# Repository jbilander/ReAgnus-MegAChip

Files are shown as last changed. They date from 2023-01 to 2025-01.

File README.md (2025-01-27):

# ReAgnus-MegAChip
A ReAgnus MegaAChip PCB that takes a Gowin FPGA with embedded PSRAM, a PLCC-84 plug and FET level shifters.

***

THIS IS WORK IN PROGRESS, HARDWARE IS VERIFIED WORKING. FIRMWARE YET TO BE DEVELOPED. BUILD AT YOUR OWN RISK.

***

<a href="pics/ReAgnus-MegAChip_pic1.jpg">
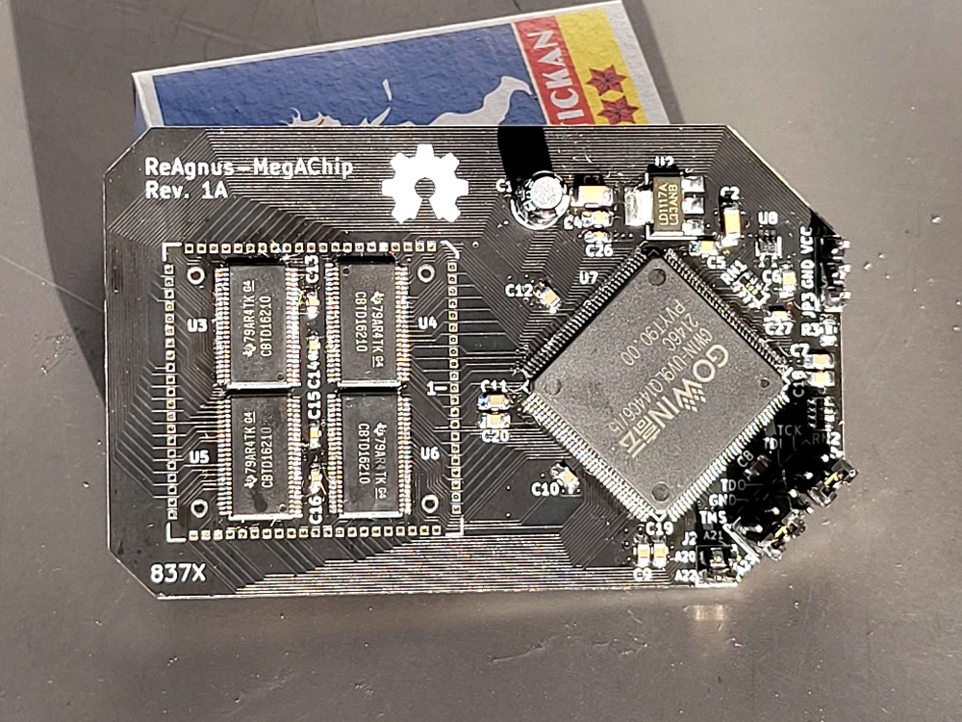
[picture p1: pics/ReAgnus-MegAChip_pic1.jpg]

</a>
<a href="pics/ReAgnus-MegAChip_pic21.png">
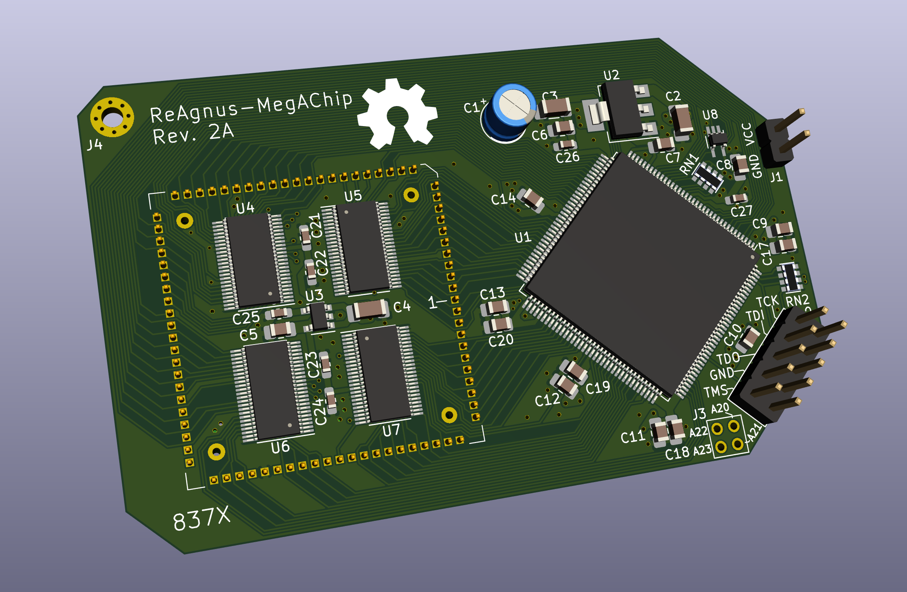
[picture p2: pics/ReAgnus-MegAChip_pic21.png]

</a>

***

<a href="pics/ReAgnus-MegAChip_pic2.jpg">
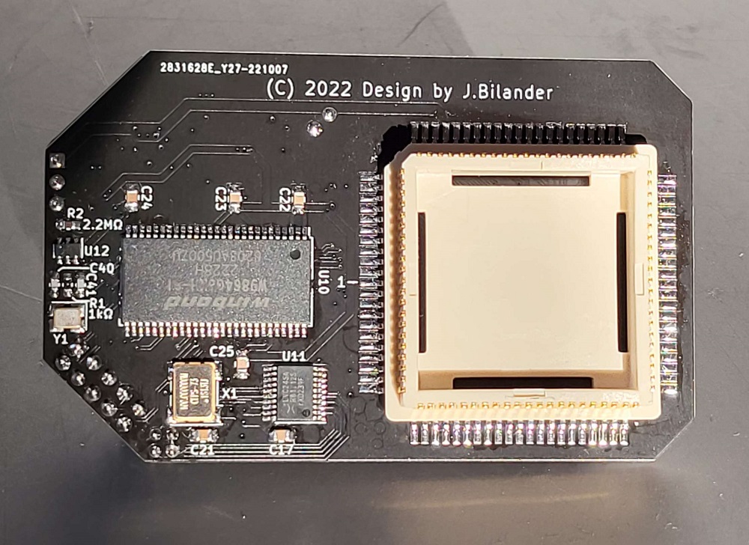
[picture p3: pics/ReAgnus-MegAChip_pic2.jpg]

</a>
<a href="pics/ReAgnus-MegAChip_pic22.png">
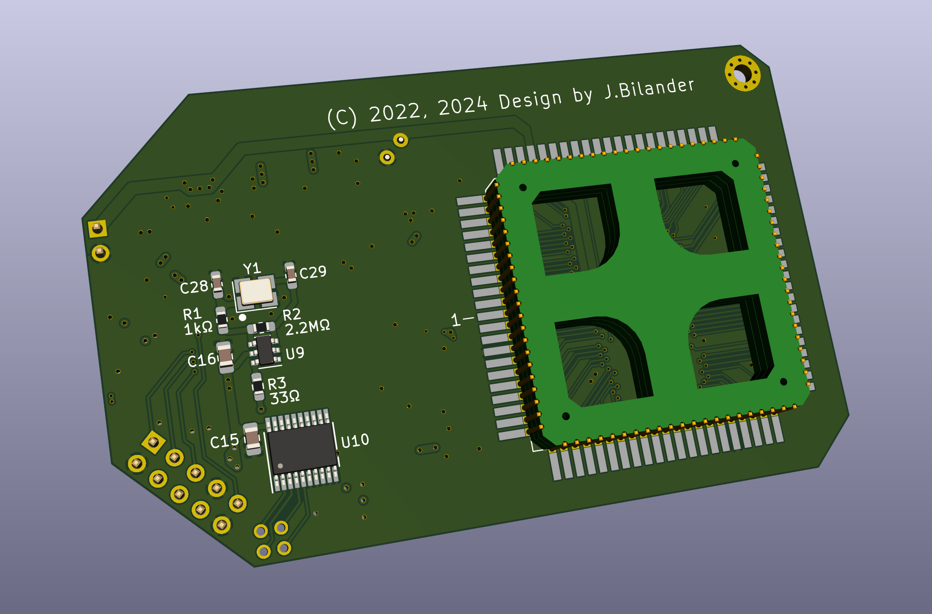
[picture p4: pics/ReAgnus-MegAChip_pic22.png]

</a>
<br />
<a href="pics/ReAgnus-MegAChip_pic23.png">
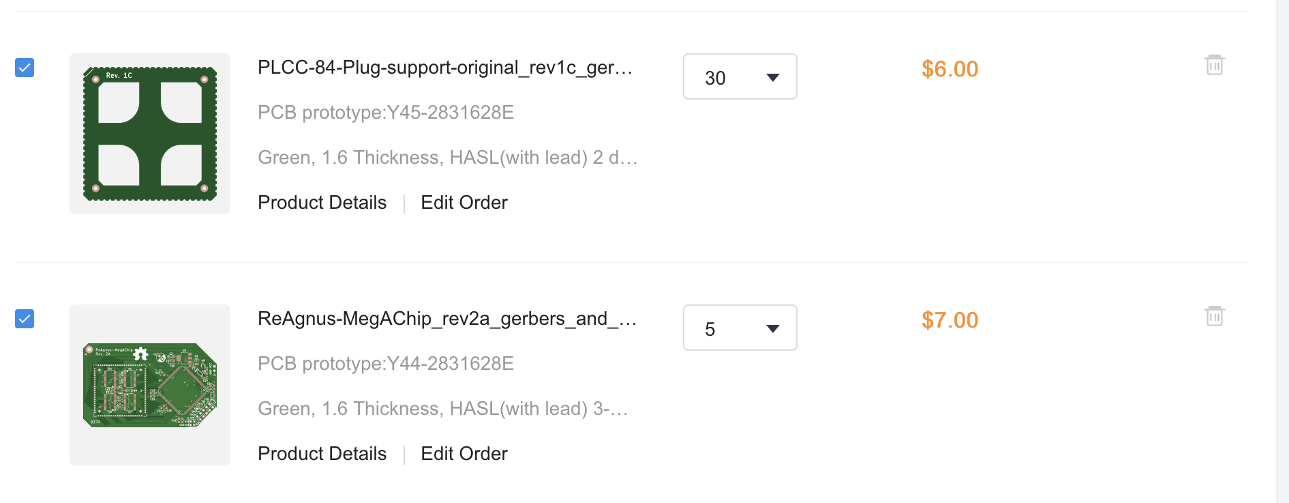
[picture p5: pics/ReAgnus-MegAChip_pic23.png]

</a>
<a href="pics/ReAgnus-MegAChip_pic24.png">
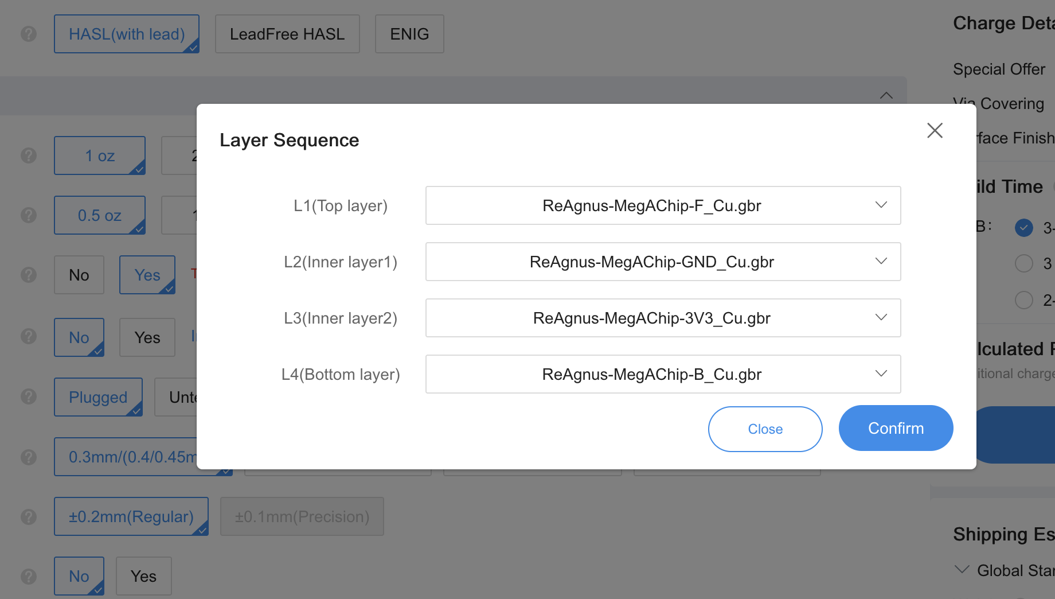
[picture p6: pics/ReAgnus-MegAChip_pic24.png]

</a>

***

***

For hi-res pics goto the hi-res folder in pics
https://github.com/jbilander/ReAgnus-MegAChip/tree/main/pics/hi-res

***

BOM Rev. 2C
---------
Designator  | Name/Value   | Package | Notes
-|-|-|-|
U1 | Gowin FPGA GW1NR-UV9LQ144PC6/I5 | LQFP-144 | FPGA - Field Programmable Gate Array, 8640 LE, 121 I/O, Embedded 64Mbit 16-bit PSRAM <br /> [GW1NR-UV9LQ144PC6/I5](https://www.mouser.com/ProductDetail/192-1NRUV9LQ144PC6I5)
U2 | Voltage Regulator 3.3V, <br /> LM1117-3.3 or <br /> AMS1117-3.3 | SOT-223 | 3.3V 1A Low Drop-Out (LDO) Voltage regulator. https://www.aliexpress.com/item/32869037691.html
U3 | Voltage Regulator 4.3V, TPS73643DBVR or <br /> ABLIC S-1132B43-M5T1U | SOT-23-5 | 4.3V LDO Voltage Regulator<br />[TPS73643DBVR](https://www.mouser.com/ProductDetail/595-TPS73643DBVR) <br />[S-1132B43-M5T1U](https://www.mouser.com/ProductDetail/628-S-1132B43-M5T1G)
U4,U5,U6,U7 | Digital Bus Switch ICs 20-Bit FET, SN74CBT16210CDGVR | TVSOP-48 | FET Level-shifter <br /> [SN74CBT16210CDGVR](https://www.mouser.com/ProductDetail/595-SN74CBT16210CDGV)
U8 | 74LVC1G07 Single Buffer With Open-Drain Output | SOT-353, SC-70-5 | [74LVC1G07](https://www.mouser.com/ProductDetail/621-74LVC1G07SE-7)
U9 | X-tal driver 74LVC1GX04  | TSOP-6 1.65x3.05mm P0.95mm | [74LVC1GX04](https://www.mouser.com/ProductDetail/771-LVC1GX04GV125)
U10 | Bus Transceiver 74LVC245APW,118 | TSSOP-20 | [74LVC245APW-T](https://www.mouser.com/ProductDetail/771-74LVC245APW-T)
U11 | Voltage Regulator 1.8V, <br /> MCP1702T-1802E/CB | SOT-23 | 1.8V Low Drop-Out (LDO) Voltage regulator. [MCP1702T1802E-CB](https://www.mouser.com/ProductDetail/579-MCP1702T1802E-CB)
U12 | Winslow PLCC-84 Plug | PLCC-84 Plug | Optionally homemade plug
U13 | PLCC-84_TH_pin_holes | Agnus_TH_plug_pins | Pins to use with homemade plug, 1.27mm pitch Long Pin 1x40P or 1x50P [Aliexpress](https://www.aliexpress.com/item/32894911767.html) Cut to length after soldering.
Y1 | 18pF Crystal 28.6363 MHz (NTSC) or 28.375 MHz (PAL) | 3.2 mm x 2.5 mm | [ECS-286.3-18-33-JEM-TR](https://www.mouser.com/ProductDetail/520-286.3-18-33-JEMT) (NTSC)<br /> [ABM8-28.375MHZ-B2-T](https://www.mouser.com/ProductDetail/815-ABM8-28.375-B2-T) (PAL)
R1 | Resistor 1k Ω | 0603 | Resistor in optional Oscillator-circuit
R2 | Resistor 2.2M Ω | 0603 | Resistor in optional Oscillator-circuit
R3 | Resistor 33 Ω | 0603 | Series resistor for CLK from U9 to avoid reflections (in optional Oscillator-circuit).
R4 | Resistor 10k Ω | 0603 | Pull-up resistor for pin 41 (PAL/NTSC-selector for A500 Rev.6A/A2000/A3000-pinout) since A500 Rev.6A doesn't have pull-up on motherboard like A2000/A3000/A3000T have. Only needed for A500 Rev.6A. but doesn't hurt to populate anyway. 
R5 | Resistor 4.7k Ω | 0603 | Pull-down resistor for TCK in JTAG.
RN1 | 4.7k or 10k Ω RES ARRAY 4 Resistors | 1206 | [CAY16-4701F4LF](https://www.mouser.com/ProductDetail/652-CAY16A-4701F4LF) or [CAY16-103J4LF](https://www.mouser.com/ProductDetail/652-CAY16-103J4LF)
RN2 | 4.7k (CAY16-4701F4LF) RES ARRAY 4 Resistors | 1206 | [CAY16-4701F4LF](https://www.mouser.com/ProductDetail/652-CAY16A-4701F4LF)
C1 | Capacitor Radial Polarized 100uF | 2.5mm pitch, Through-Hole | [ECE-A0JKA101I](https://www.mouser.com/ProductDetail/667-ECE-A0JKA101I)
C2-C4 | Capacitor 10uF | 1206 | 
C5 | Capacitor 1uF | 0805 | 
C6 | Capacitor 10uF | 0805 |
C9 | Capacitor 1uF | 0805 |
C7,C8,C10-C16 | Capacitor 0.1uF = 100nF | 0805 |
C17-C19 | Capacitor 0.01uF = 10nF | 0805 (or 0603) |
C20 | Capacitor 0.1uF = 100nF | 0603 | Decoupling cap for U8
C21-C24 | Capacitor 0.1uF = 100nF | 0603 | Decoupling caps for U4-U7
C25 | Capacitor 0.1uF = 100nF | 0603 | Optional cap for U3, NR (Noise Reduction) pin 4 on TPS73643DBVR, this pin is NC on ABLIC S-1200B43-M5T1U
C26 | Capacitor 0.01uF = 10nF | 0603 |
C27-C28 | Capacitor 0.1uF = 100nF | 0603 |
C29-C30 | Multilayer Ceramic Capacitors MLCC - 32pF | 0603 | [06031A320FAT2A ](https://www.mouser.com/ProductDetail/581-06031A320FAT2A) Caps for optional oscillator circuit 
L1 | (Ferrite Bead 600ohms 100MHz .5A Monolithic) or 0 Ω resistor  | 0805 | [HZ0805E601R-10](https://www.mouser.com/ProductDetail/875-HZ0805E601R-10) or 0 Ω resistor 
J1 | VCC/GND Power Header Male | TH 1 x 2 Pin, 2.54mm pitch | For external power supply to allow programming of device when not plugged into the Amiga socket.
J2 | JTAG Pin Header Male | TH 2 x 5 Pin, 2.54mm pitch|
J3 | A20-A23 Pin Header Male | TH 2 x 2 Pin, 2.00mm pitch | Input Address lines for jumper-wires A20-A23
J4 | GND MountingHole_2.2mm_M2_Pad_Via | nut and bolt M2 size | for solid grounding via a ring lug connector and a thick jumper wire to Motherboard

***

Select one of the crystals 28.375 MHz (PAL) or 28.6363 MHz for the optional onboard oscillator circuit. Probably you want to select PAL/NTSC opposite to what your CLK on motherboard has, this in order to be able to switch between native PAL/NTSC with only a JP-setting on the MegaChip board.
***

<a href="pics/ReAgnus-MegAChip_pic5.png">
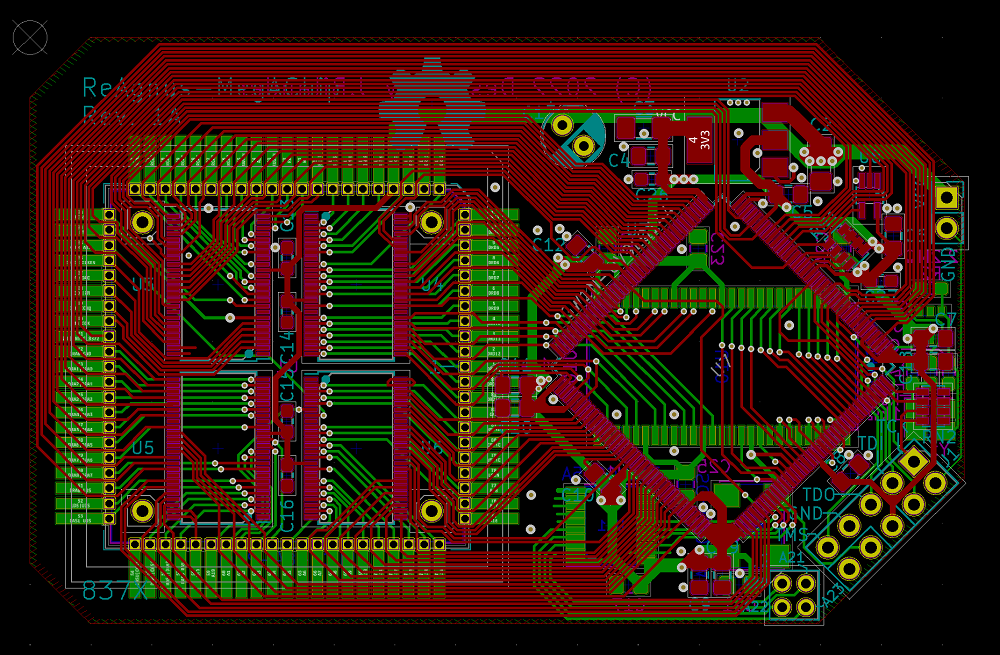
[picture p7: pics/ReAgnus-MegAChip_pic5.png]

</a>
<a href="pics/ReAgnus-MegAChip_pic6.png">
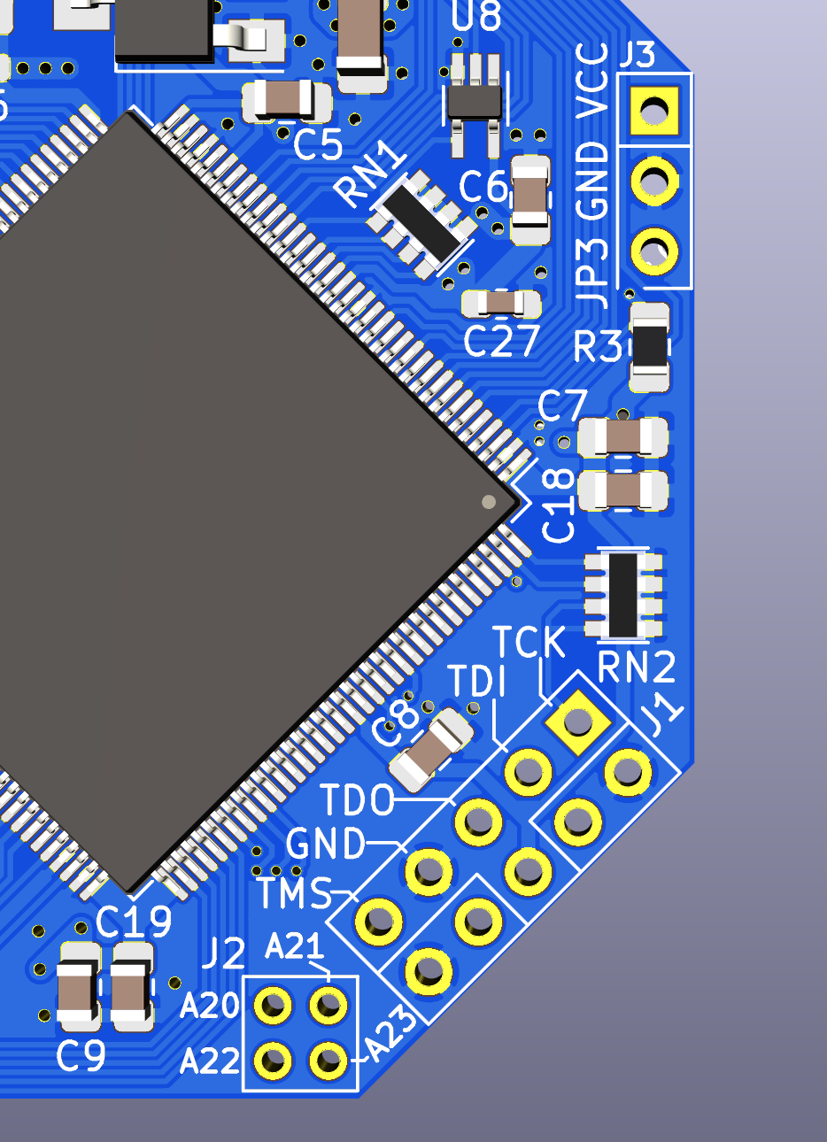
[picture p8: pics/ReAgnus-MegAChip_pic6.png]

</a>

***

<a href="pics/ReAgnus-MegAChip_pic7.jpg">
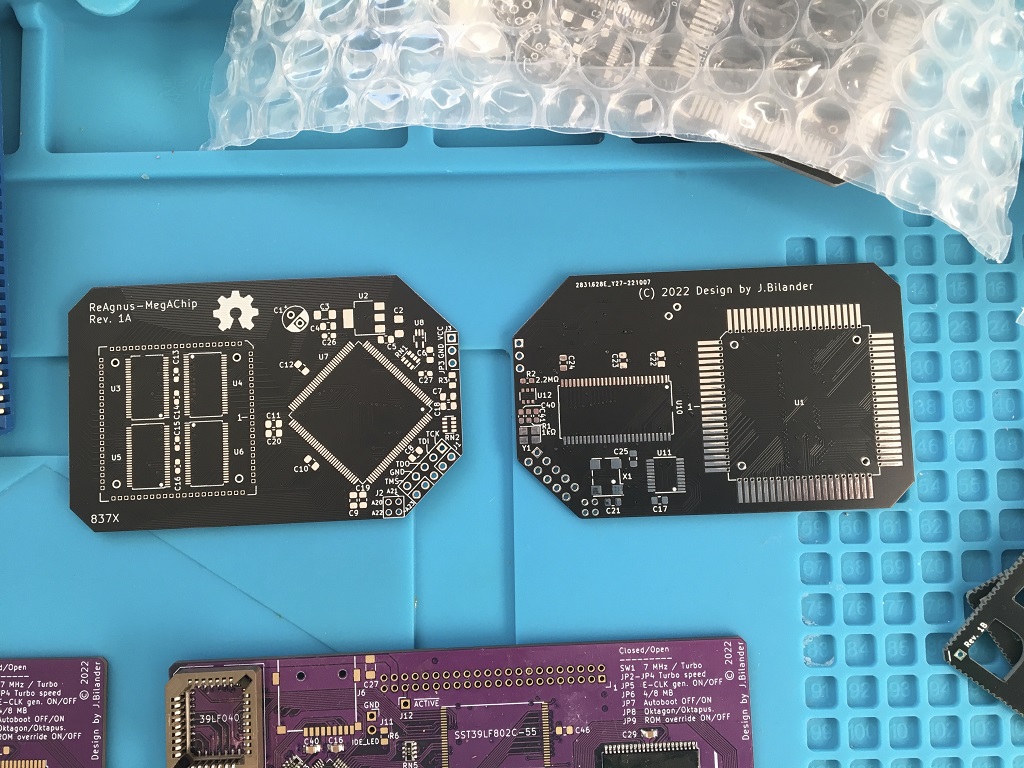
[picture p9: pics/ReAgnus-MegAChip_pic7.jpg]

</a>
<a href="pics/ReAgnus-MegAChip_pic8.jpg">
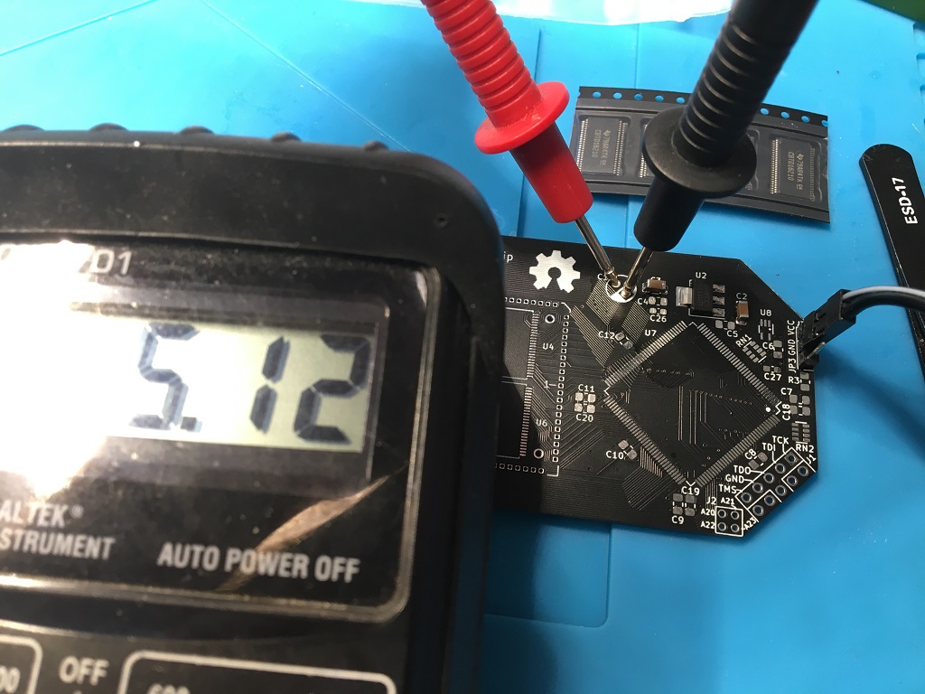
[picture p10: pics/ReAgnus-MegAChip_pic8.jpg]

</a>

***

<a href="pics/ReAgnus-MegAChip_pic9.jpg">
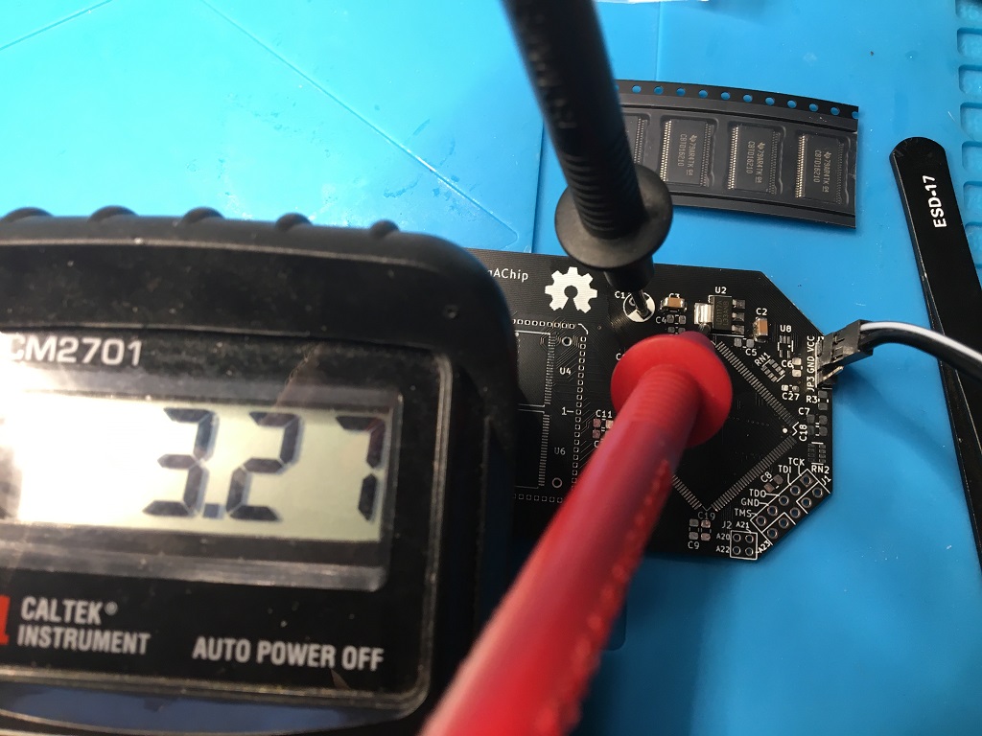
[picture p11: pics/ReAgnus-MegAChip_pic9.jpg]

</a>
<a href="pics/ReAgnus-MegAChip_pic12.jpg">
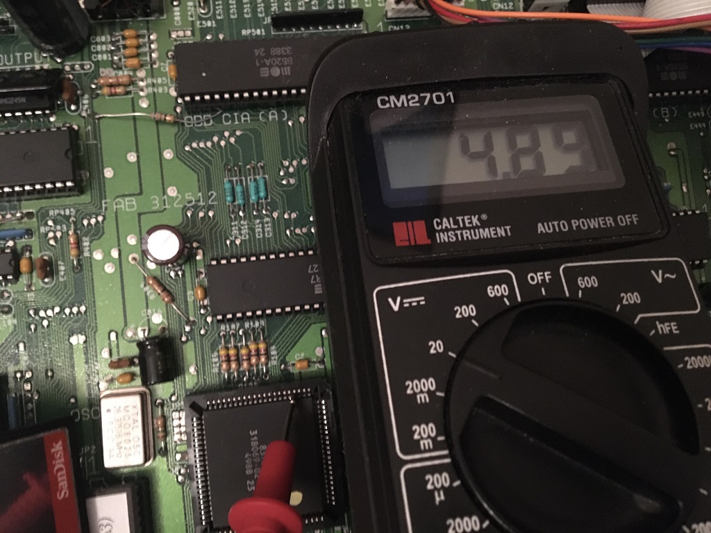
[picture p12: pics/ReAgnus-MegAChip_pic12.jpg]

</a>

***

<a href="pics/ReAgnus-MegAChip_pic10.jpg">
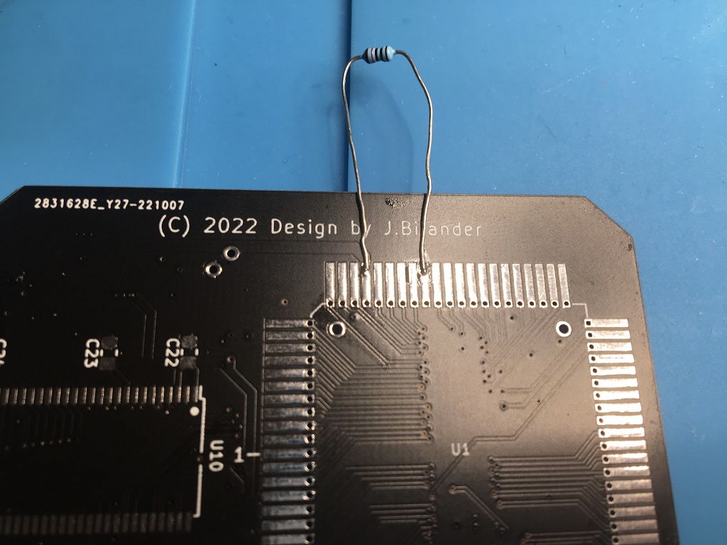
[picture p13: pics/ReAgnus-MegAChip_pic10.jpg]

</a>
<a href="pics/ReAgnus-MegAChip_pic11.jpg">
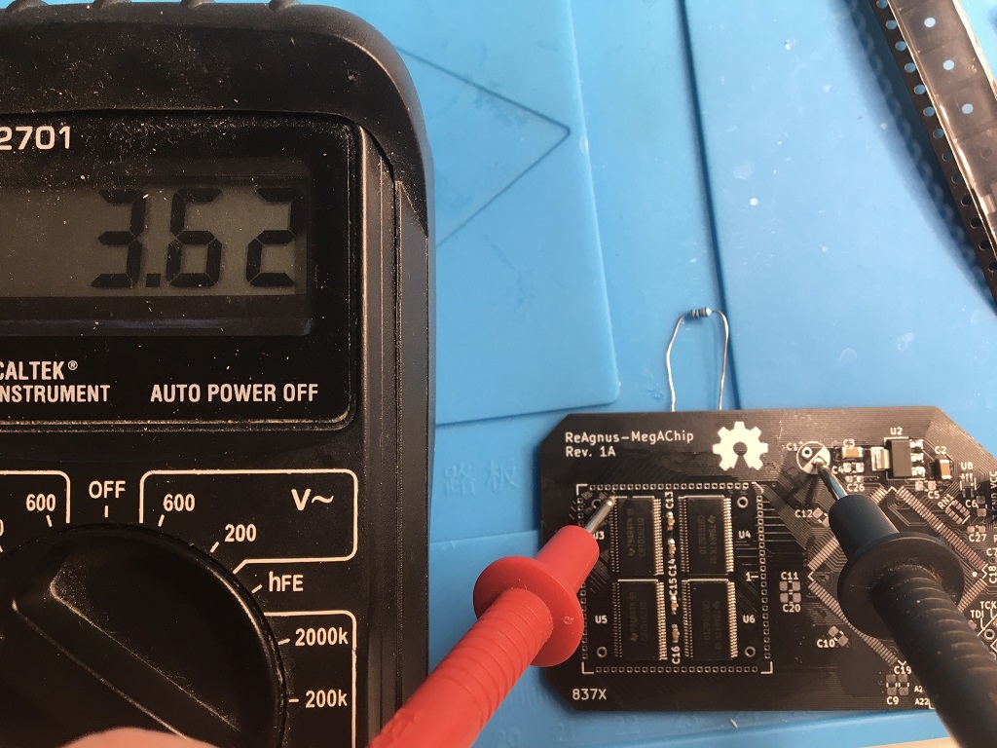
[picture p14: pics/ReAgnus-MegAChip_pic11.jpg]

</a>

***

<a href="pics/ReAgnus-MegAChip_pic13.jpg">
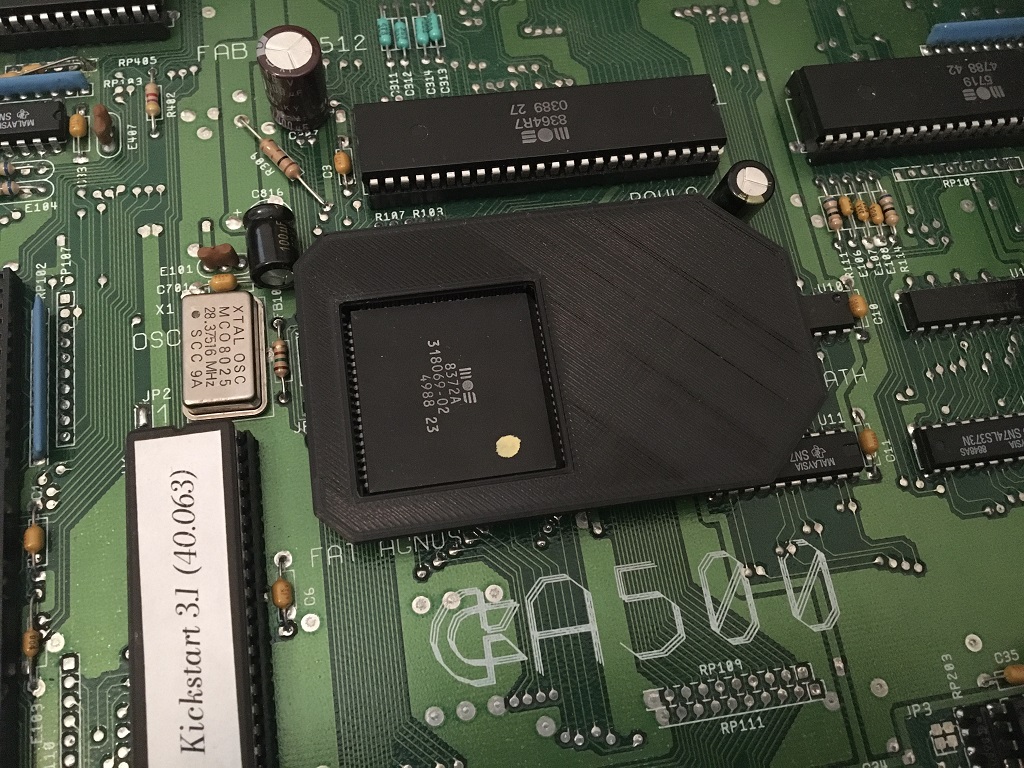
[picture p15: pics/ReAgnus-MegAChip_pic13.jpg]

</a>
<a href="pics/A500_plus_ReAgnus_MegAChip_board.png">
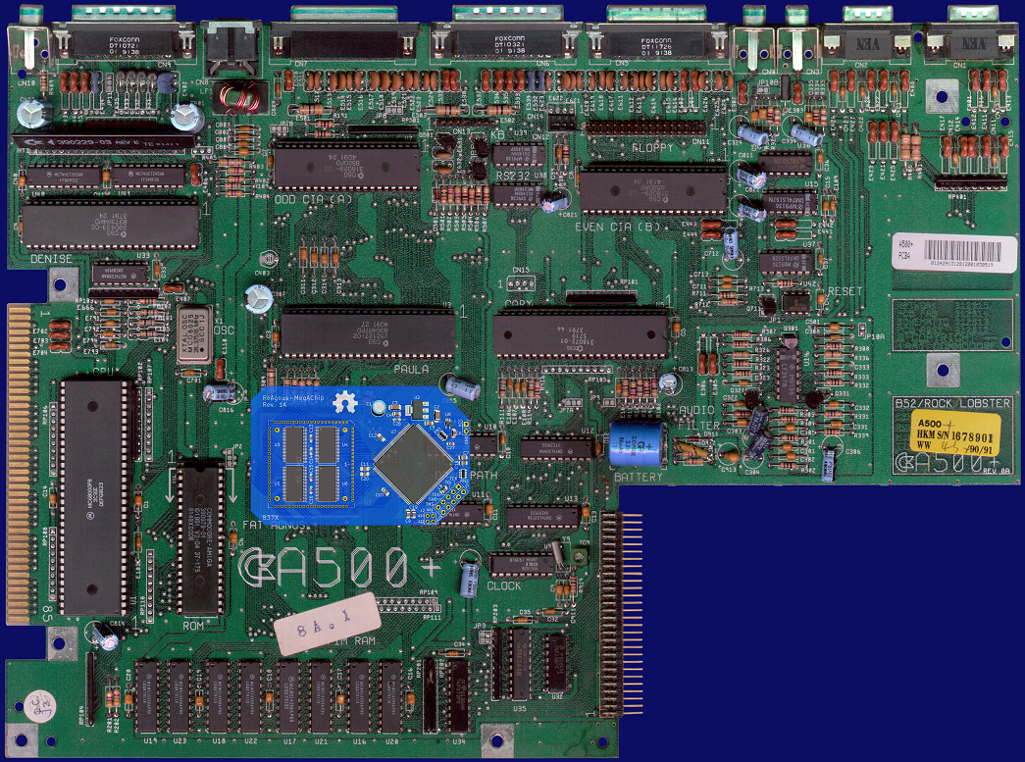
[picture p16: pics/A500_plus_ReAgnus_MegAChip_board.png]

</a>

***

<a href="pics/A500_rev5_ReAgnus_MegAChip_board.png">
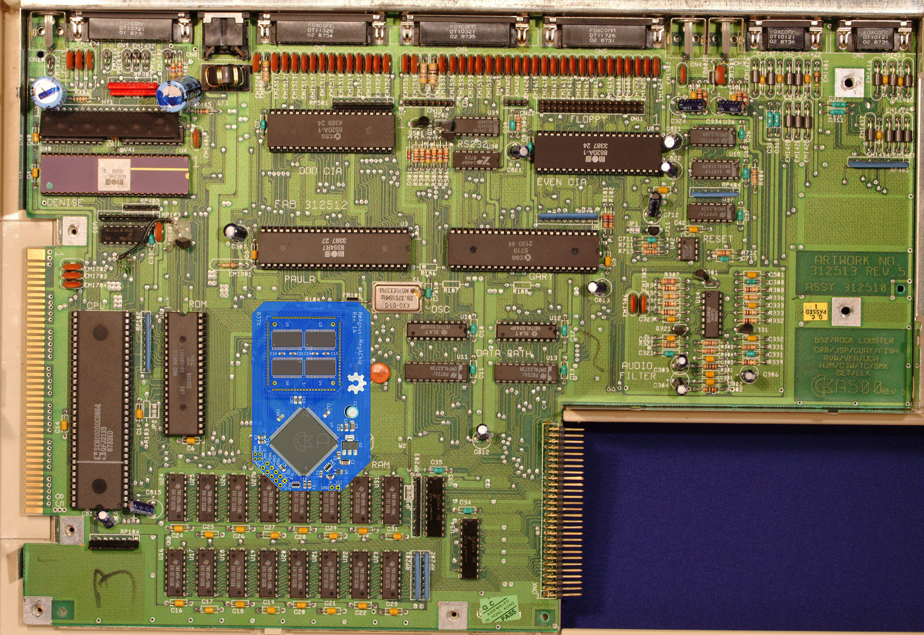
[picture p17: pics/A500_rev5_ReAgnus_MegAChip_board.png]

</a>
<a href="pics/A500_rev6a_ReAgnus_MegAChip_board.png">
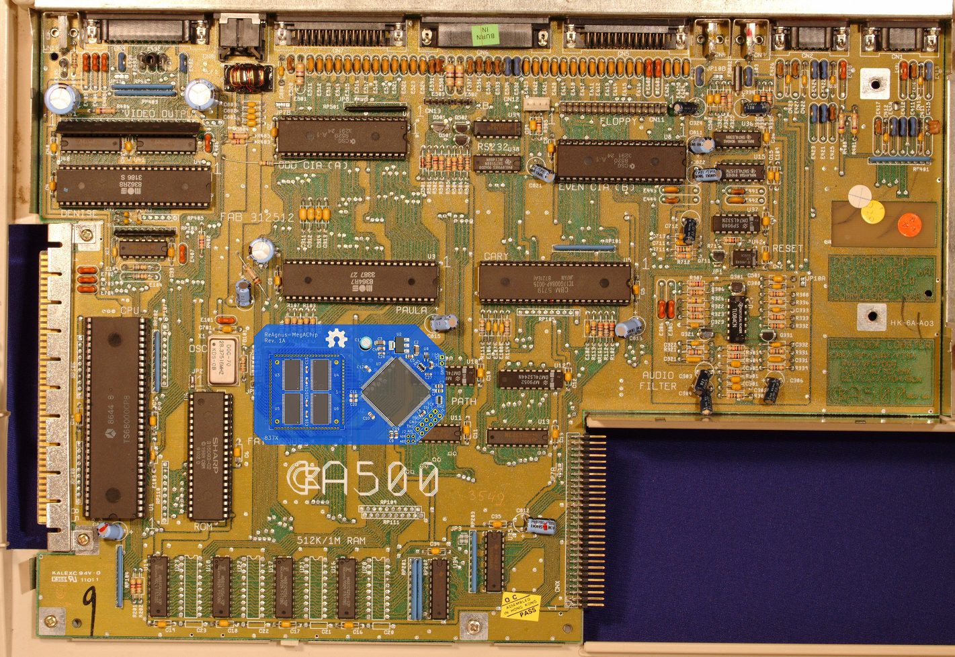
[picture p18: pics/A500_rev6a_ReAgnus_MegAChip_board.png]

</a>

***

<a href="pics/A2000_ReAgnus_MegAChip_board.png">
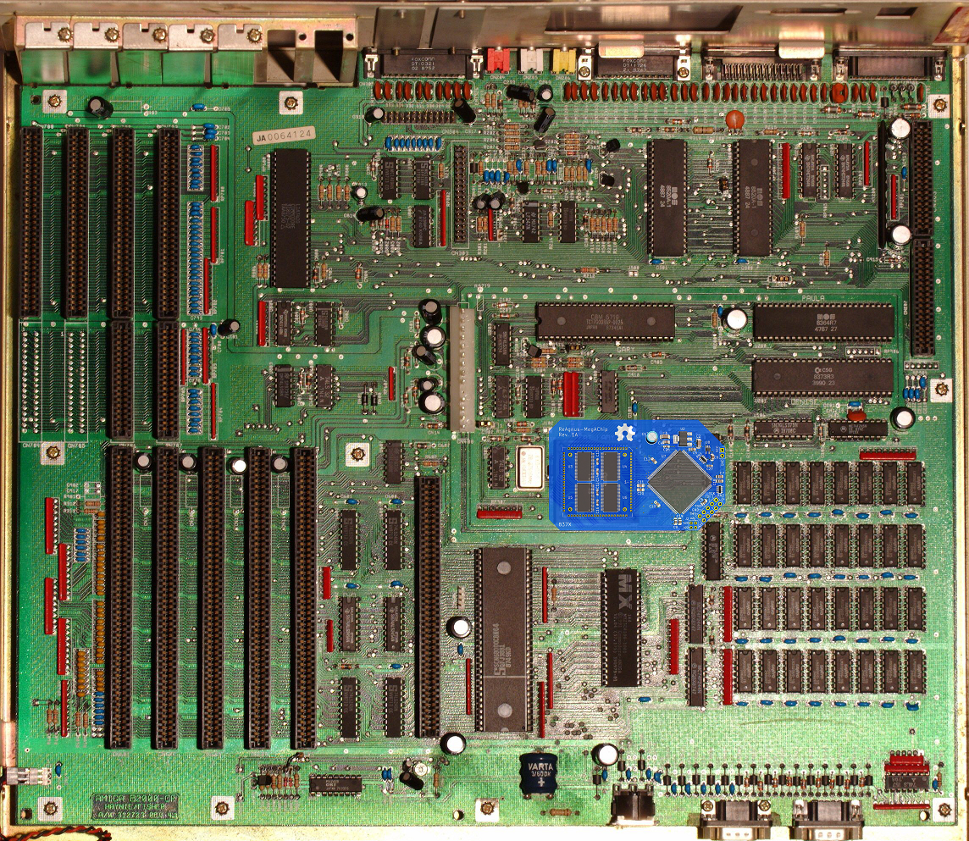
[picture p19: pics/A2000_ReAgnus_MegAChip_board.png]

</a>
<a href="pics/A3000_ReAgnus_MegAChip_board.png">
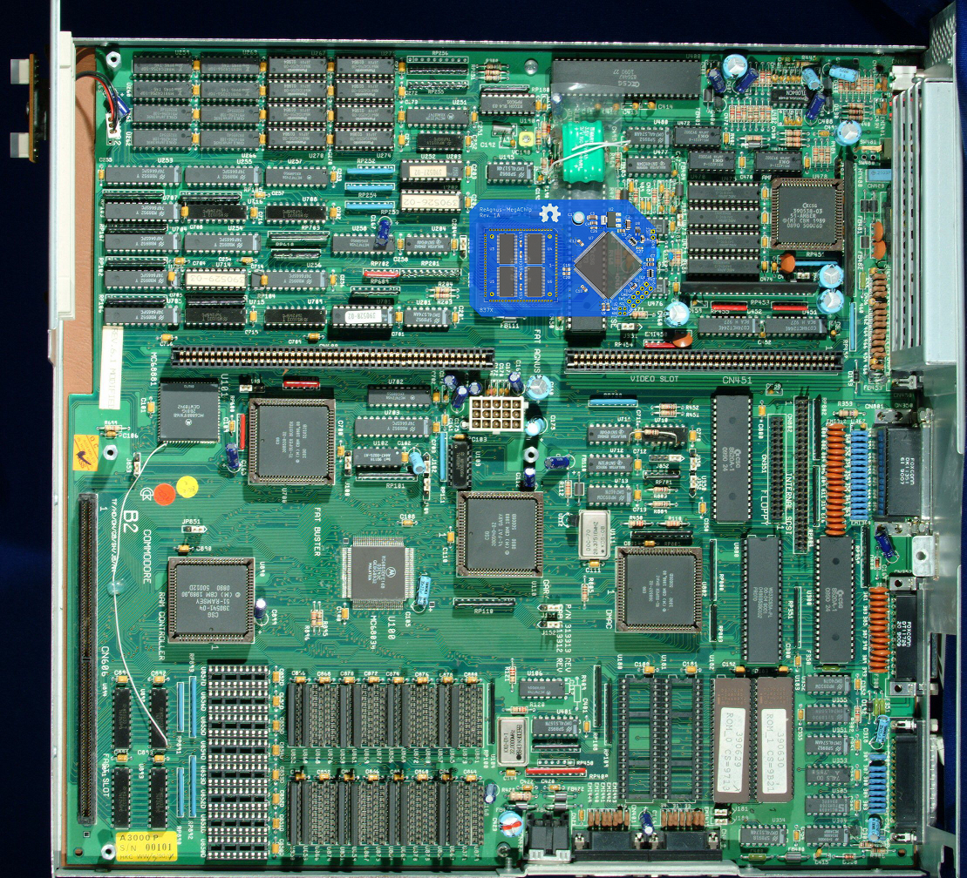
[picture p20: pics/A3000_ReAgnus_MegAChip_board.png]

</a>

***

<a href="pics/ReAgnus-MegAChip_pic14.jpg">
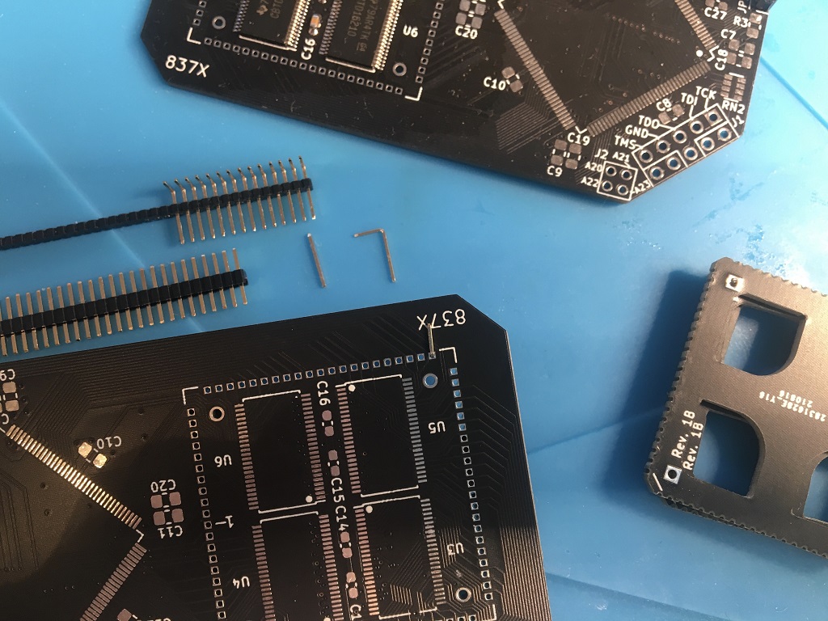
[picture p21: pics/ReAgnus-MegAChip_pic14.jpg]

</a>
<a href="pics/ReAgnus-MegAChip_pic15.jpg">
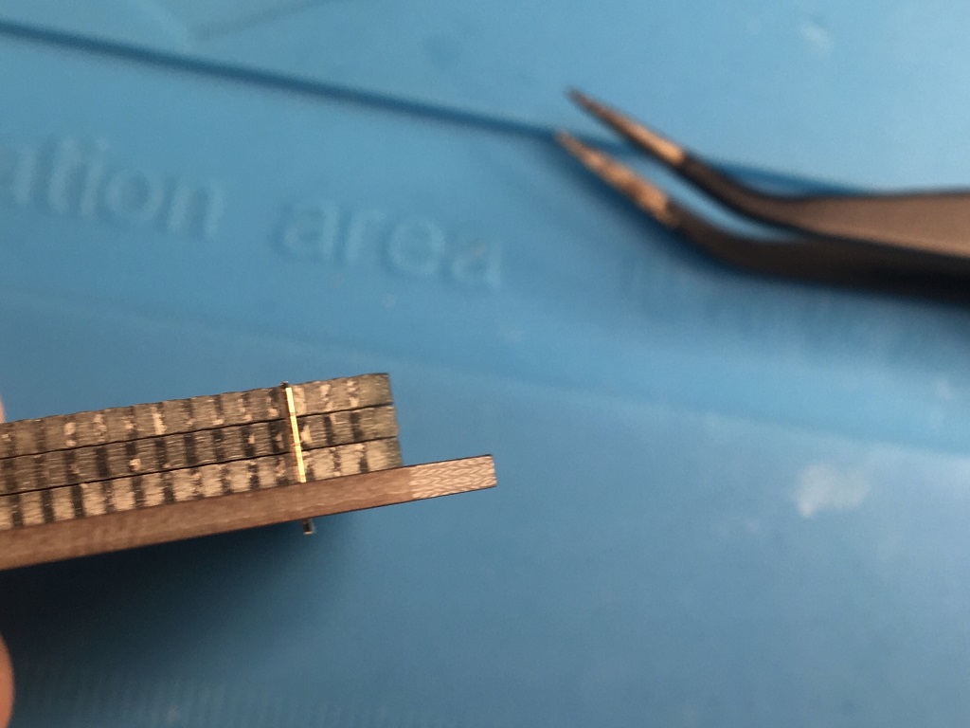
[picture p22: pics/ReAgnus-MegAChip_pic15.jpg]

</a>

***

<a href="pics/ReAgnus-MegAChip_pic16.jpg">
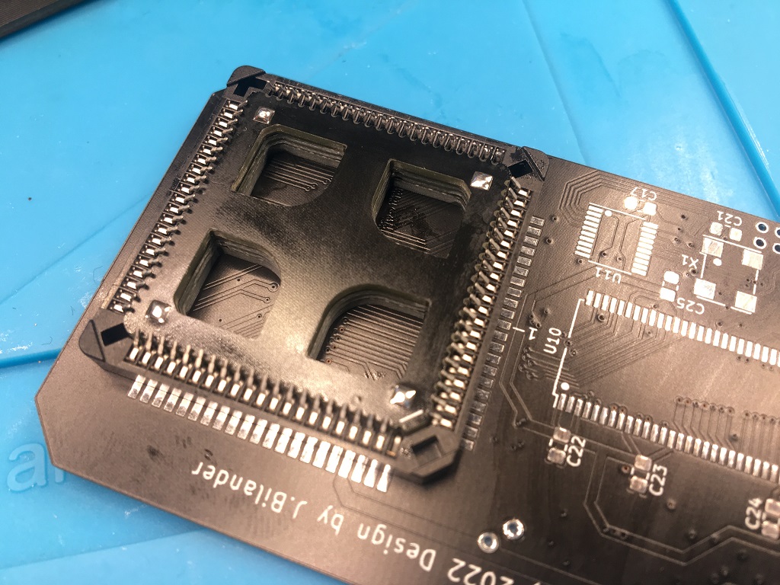
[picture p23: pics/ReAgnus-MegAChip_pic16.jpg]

</a>
<a href="pics/ReAgnus-MegAChip_pic17.jpg">
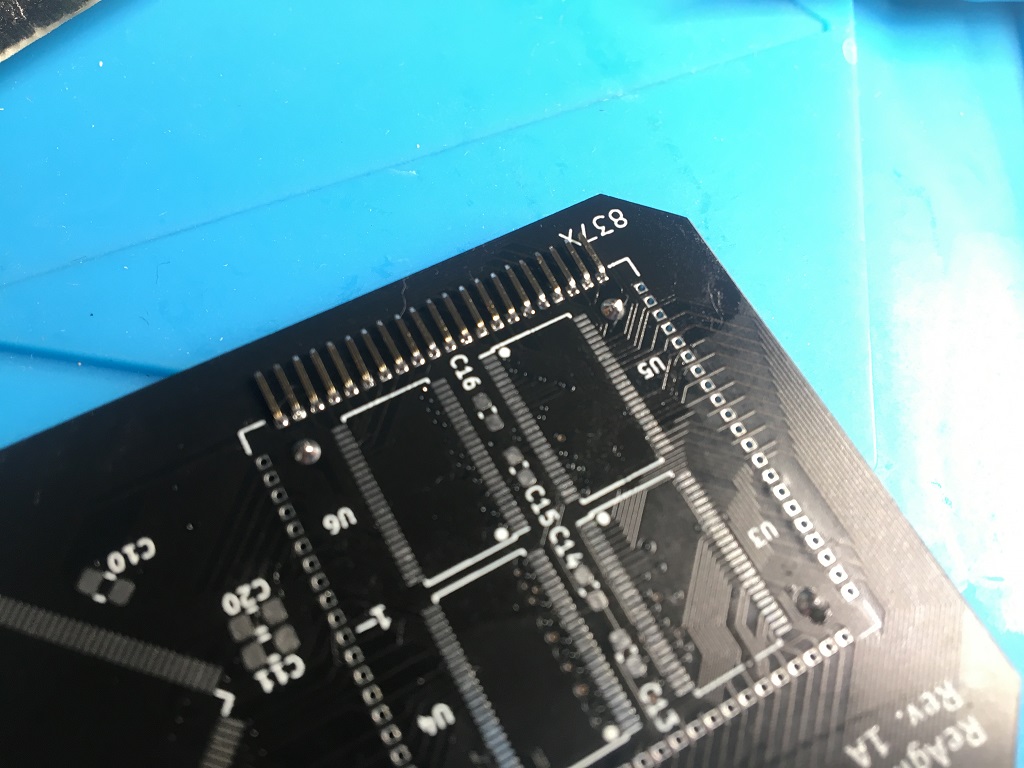
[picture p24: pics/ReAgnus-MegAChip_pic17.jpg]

</a>

***

<a href="pics/ReAgnus-MegAChip_pic18.jpg">
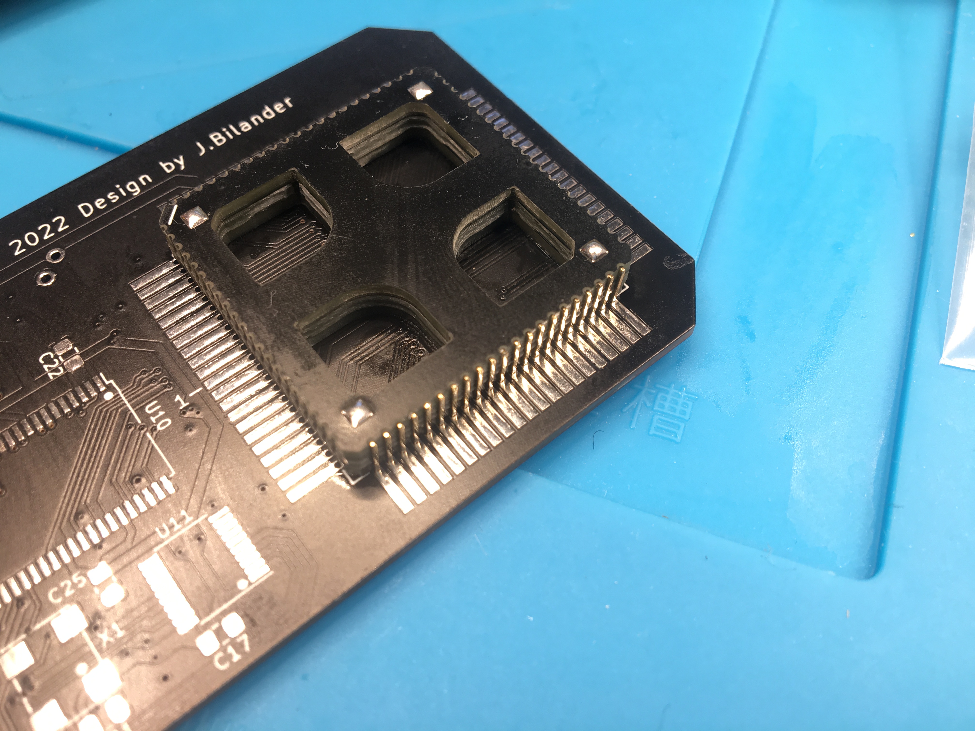
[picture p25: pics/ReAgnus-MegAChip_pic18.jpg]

</a>
<a href="pics/ReAgnus-MegAChip_pic19.png">
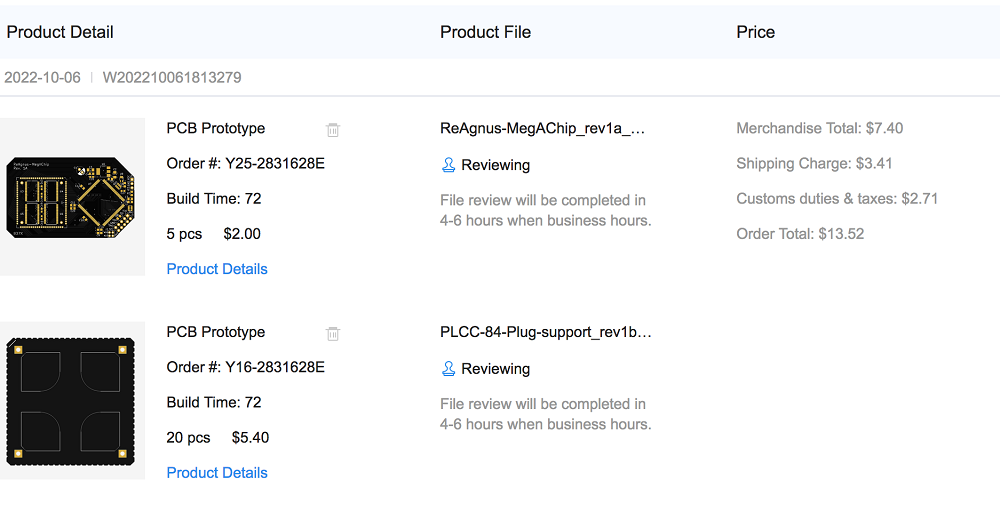
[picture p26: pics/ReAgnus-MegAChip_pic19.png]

</a>

***

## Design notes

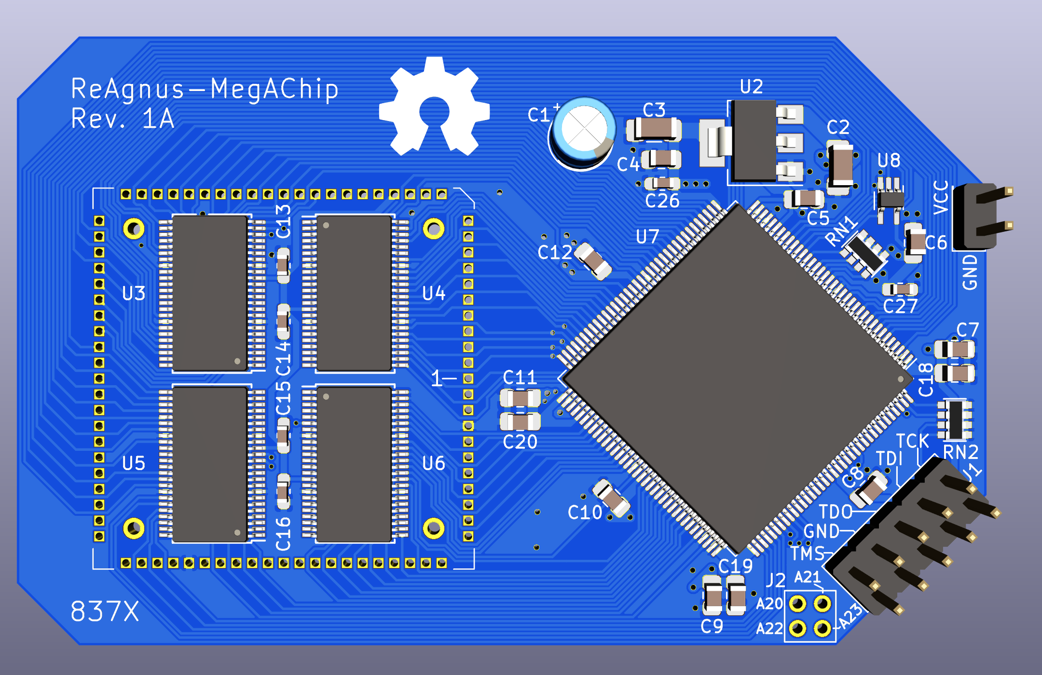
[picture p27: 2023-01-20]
pics/hi-res/ReAgnus-MegAChip_pic3.png

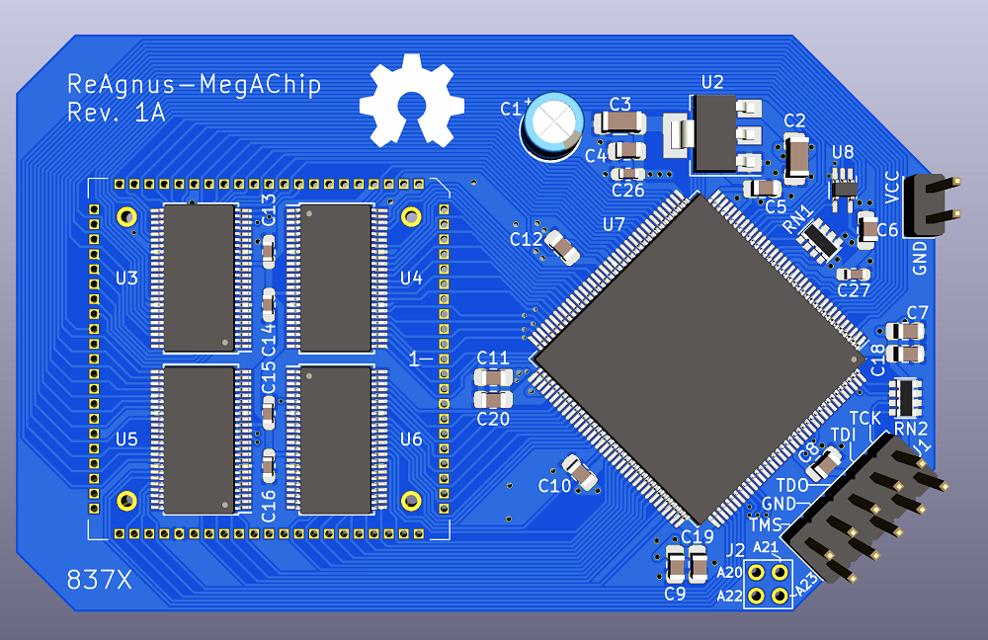
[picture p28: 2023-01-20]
pics/ReAgnus-MegAChip_pic3.png

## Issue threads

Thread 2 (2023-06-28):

WIP Firmware?

Sgw32, 2023-06-28:
Hi,

Many thanks for the project! Maybe it is also possible to share the WIP firmware to check and test the device?

jbilander, 2023-06-29:
Hi,

You will have to ask Niklas (https://github.com/niklasekstrom/) about that. He tried his firmware for ReAgnus on this board but it didn't work. We are not sure why. It might be related to signal intergrity this board being only a two layer board compared to ReAgnus 4 layer, or it might have to do something with the timings Gowin FPGA vs Intel FPGA. I'm not sure if he has tinkered anything more with the MegAChip-board he got.

niklasekstrom, 2023-06-29:
As I have written elsewhere, I'm not inclined to release the firmware until there is a version of ReAgnus that is fully working. The reason is that if I release it and someone gets it working, then with high likelihood they will keep the changes to themselves and try to make money off of it rather than contribute the changes back, even though the license is clear that this is not allowed. It's a shame that this is the situation we find ourselves in the Amiga/retro community.

Also, if there is anything that you can do to influence Russia to end the invasion of Ukraine and to stop murdering the Ukrainian people, then please do so!

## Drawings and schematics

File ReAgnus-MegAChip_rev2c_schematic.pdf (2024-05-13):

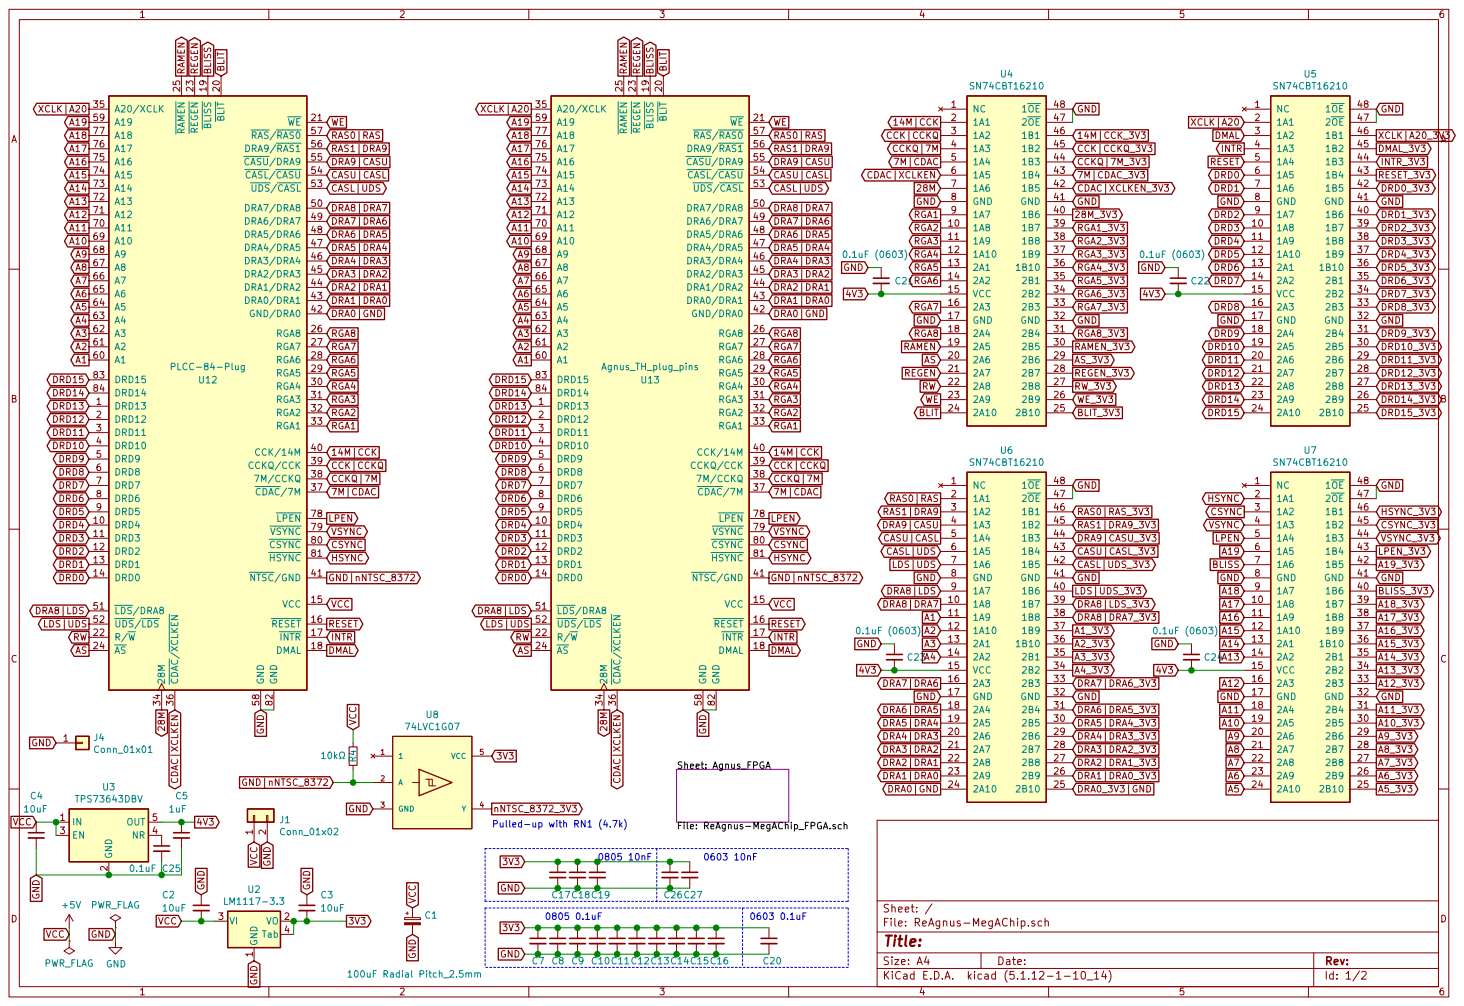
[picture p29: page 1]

File: ReAgnus-MegAChip.sch Sheet: / Sheet: Agnus_FPGA

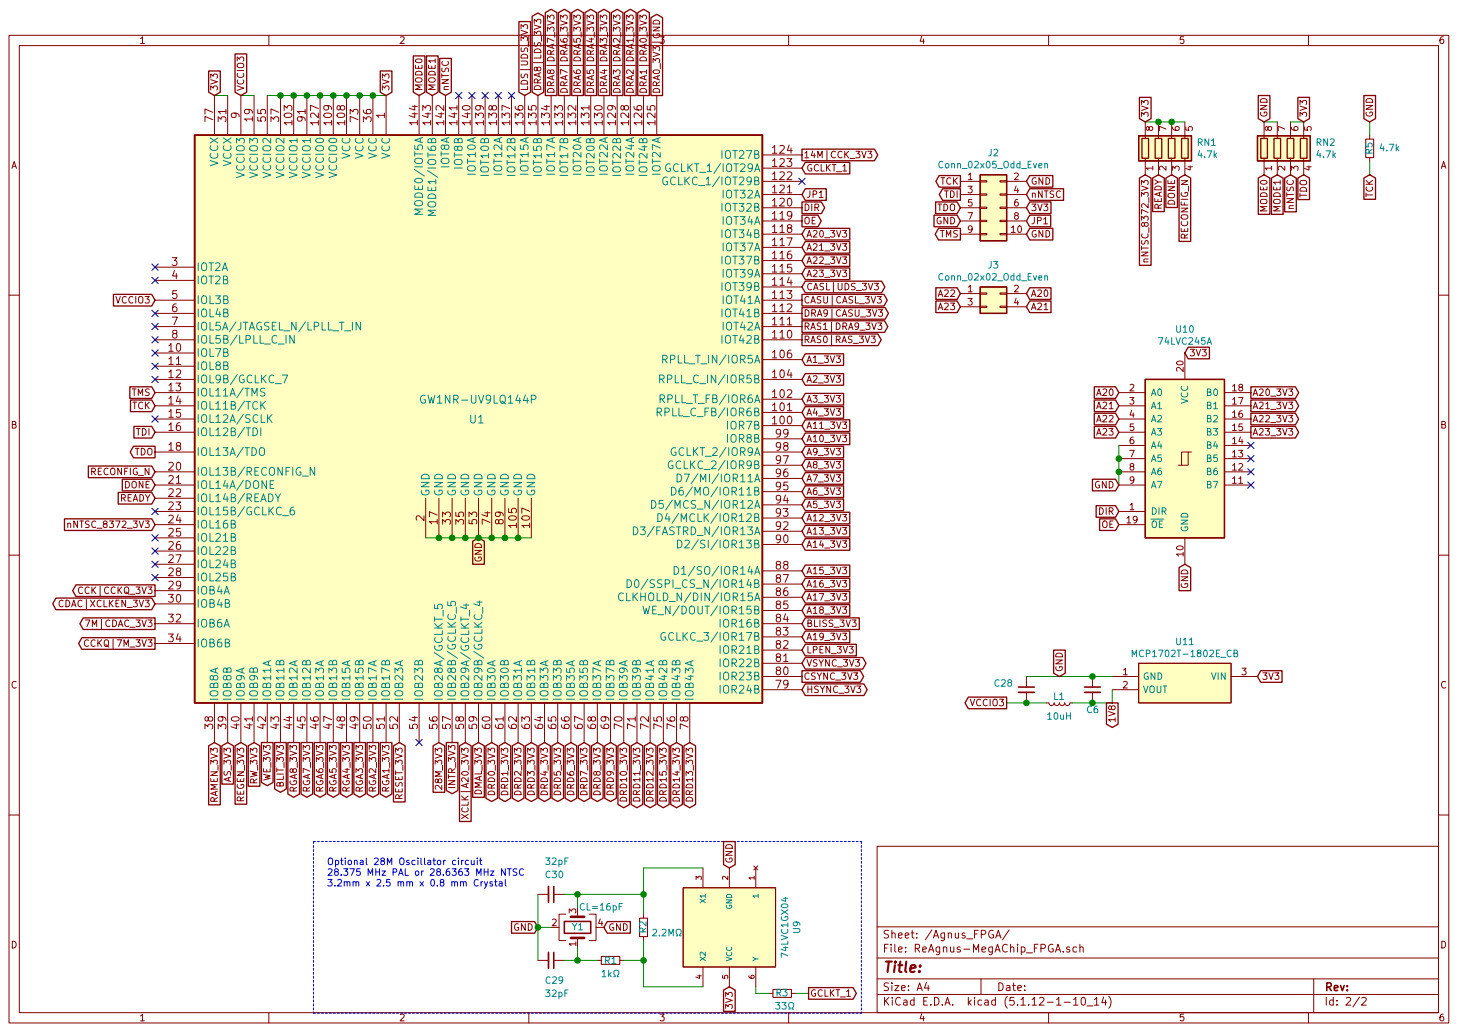
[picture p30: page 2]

6 U9 74LVC1GX04 DIR 1 GND 10 B7 11 B6 12 B5 13 B4 14 B3 15 B2 16 B1 17 B0 18 OE 19 A0 2 VCC 20 A1 3 A2 4 A3 5 A4 6 A5 7 A6 8 A7 9 U10

Optional 28M Oscillator circuit 28.375 MHz PAL or 28.6363 MHz NTSC

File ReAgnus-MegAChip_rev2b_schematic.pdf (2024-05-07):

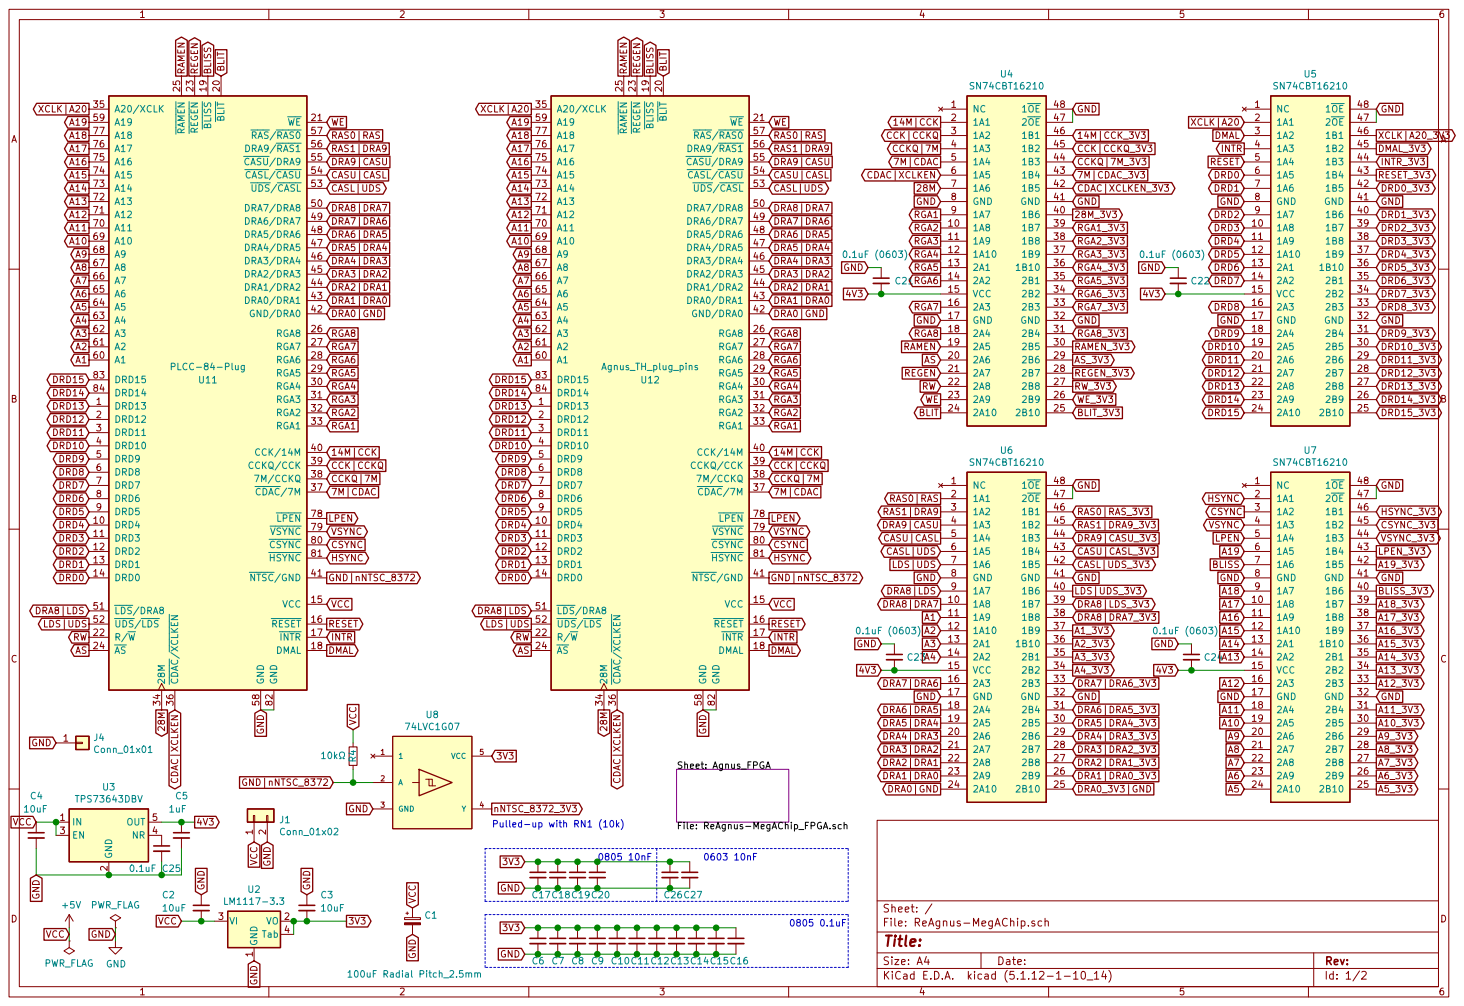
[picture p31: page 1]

2 EN 3 NR 4 OUT 5 U3 TPS73643DBV C8 C11 CSYNC

File: ReAgnus-MegAChip.sch Sheet: / Sheet: Agnus_FPGA

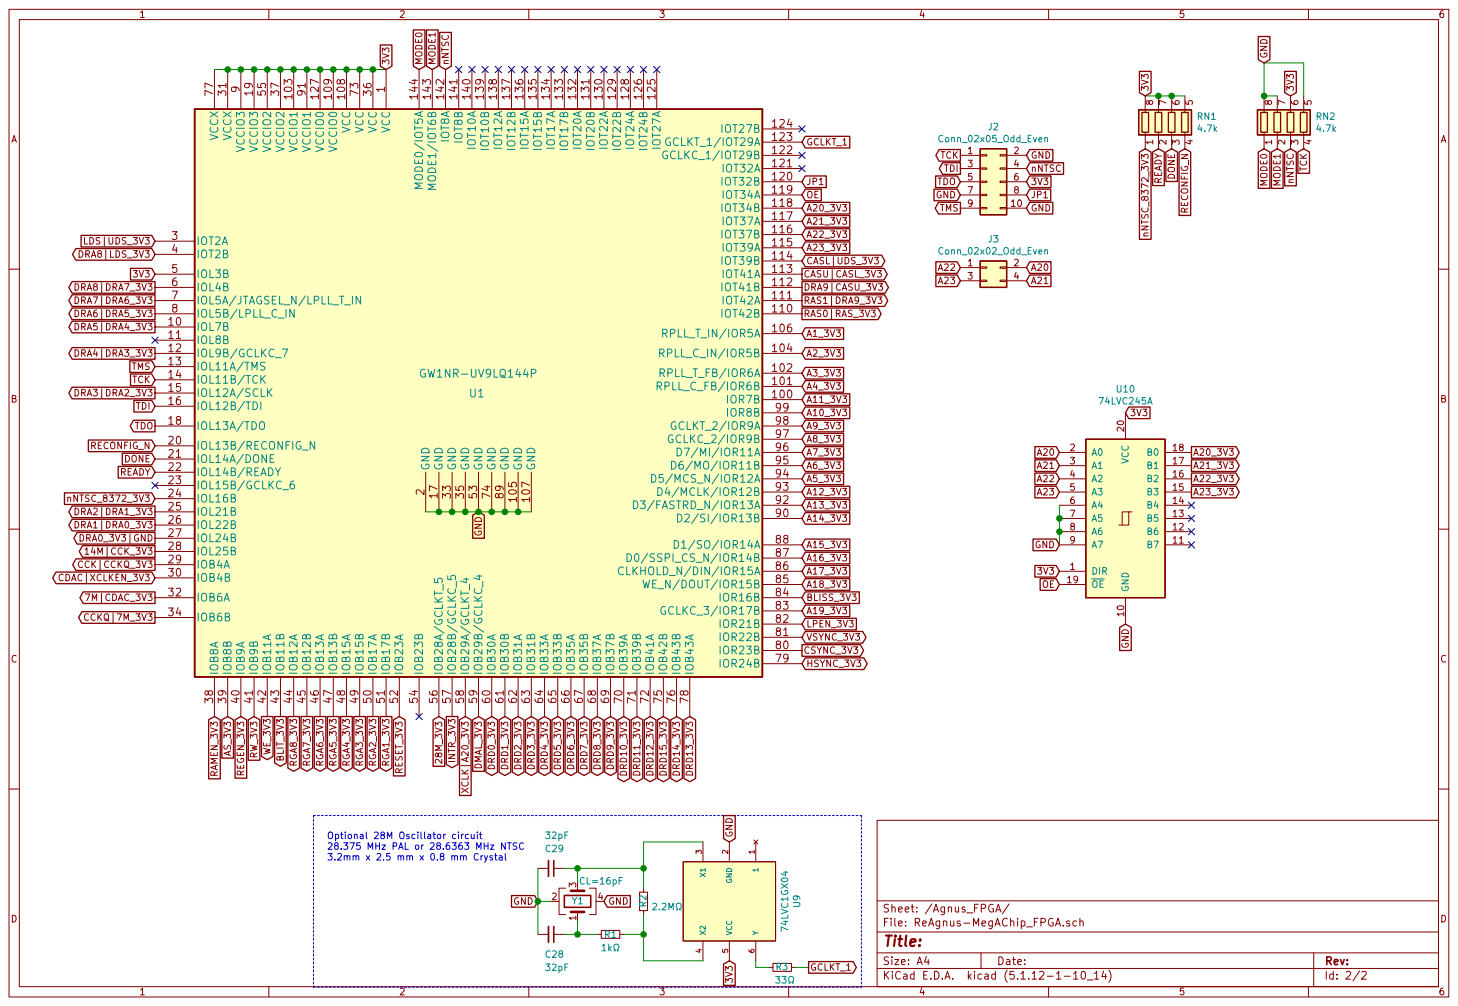
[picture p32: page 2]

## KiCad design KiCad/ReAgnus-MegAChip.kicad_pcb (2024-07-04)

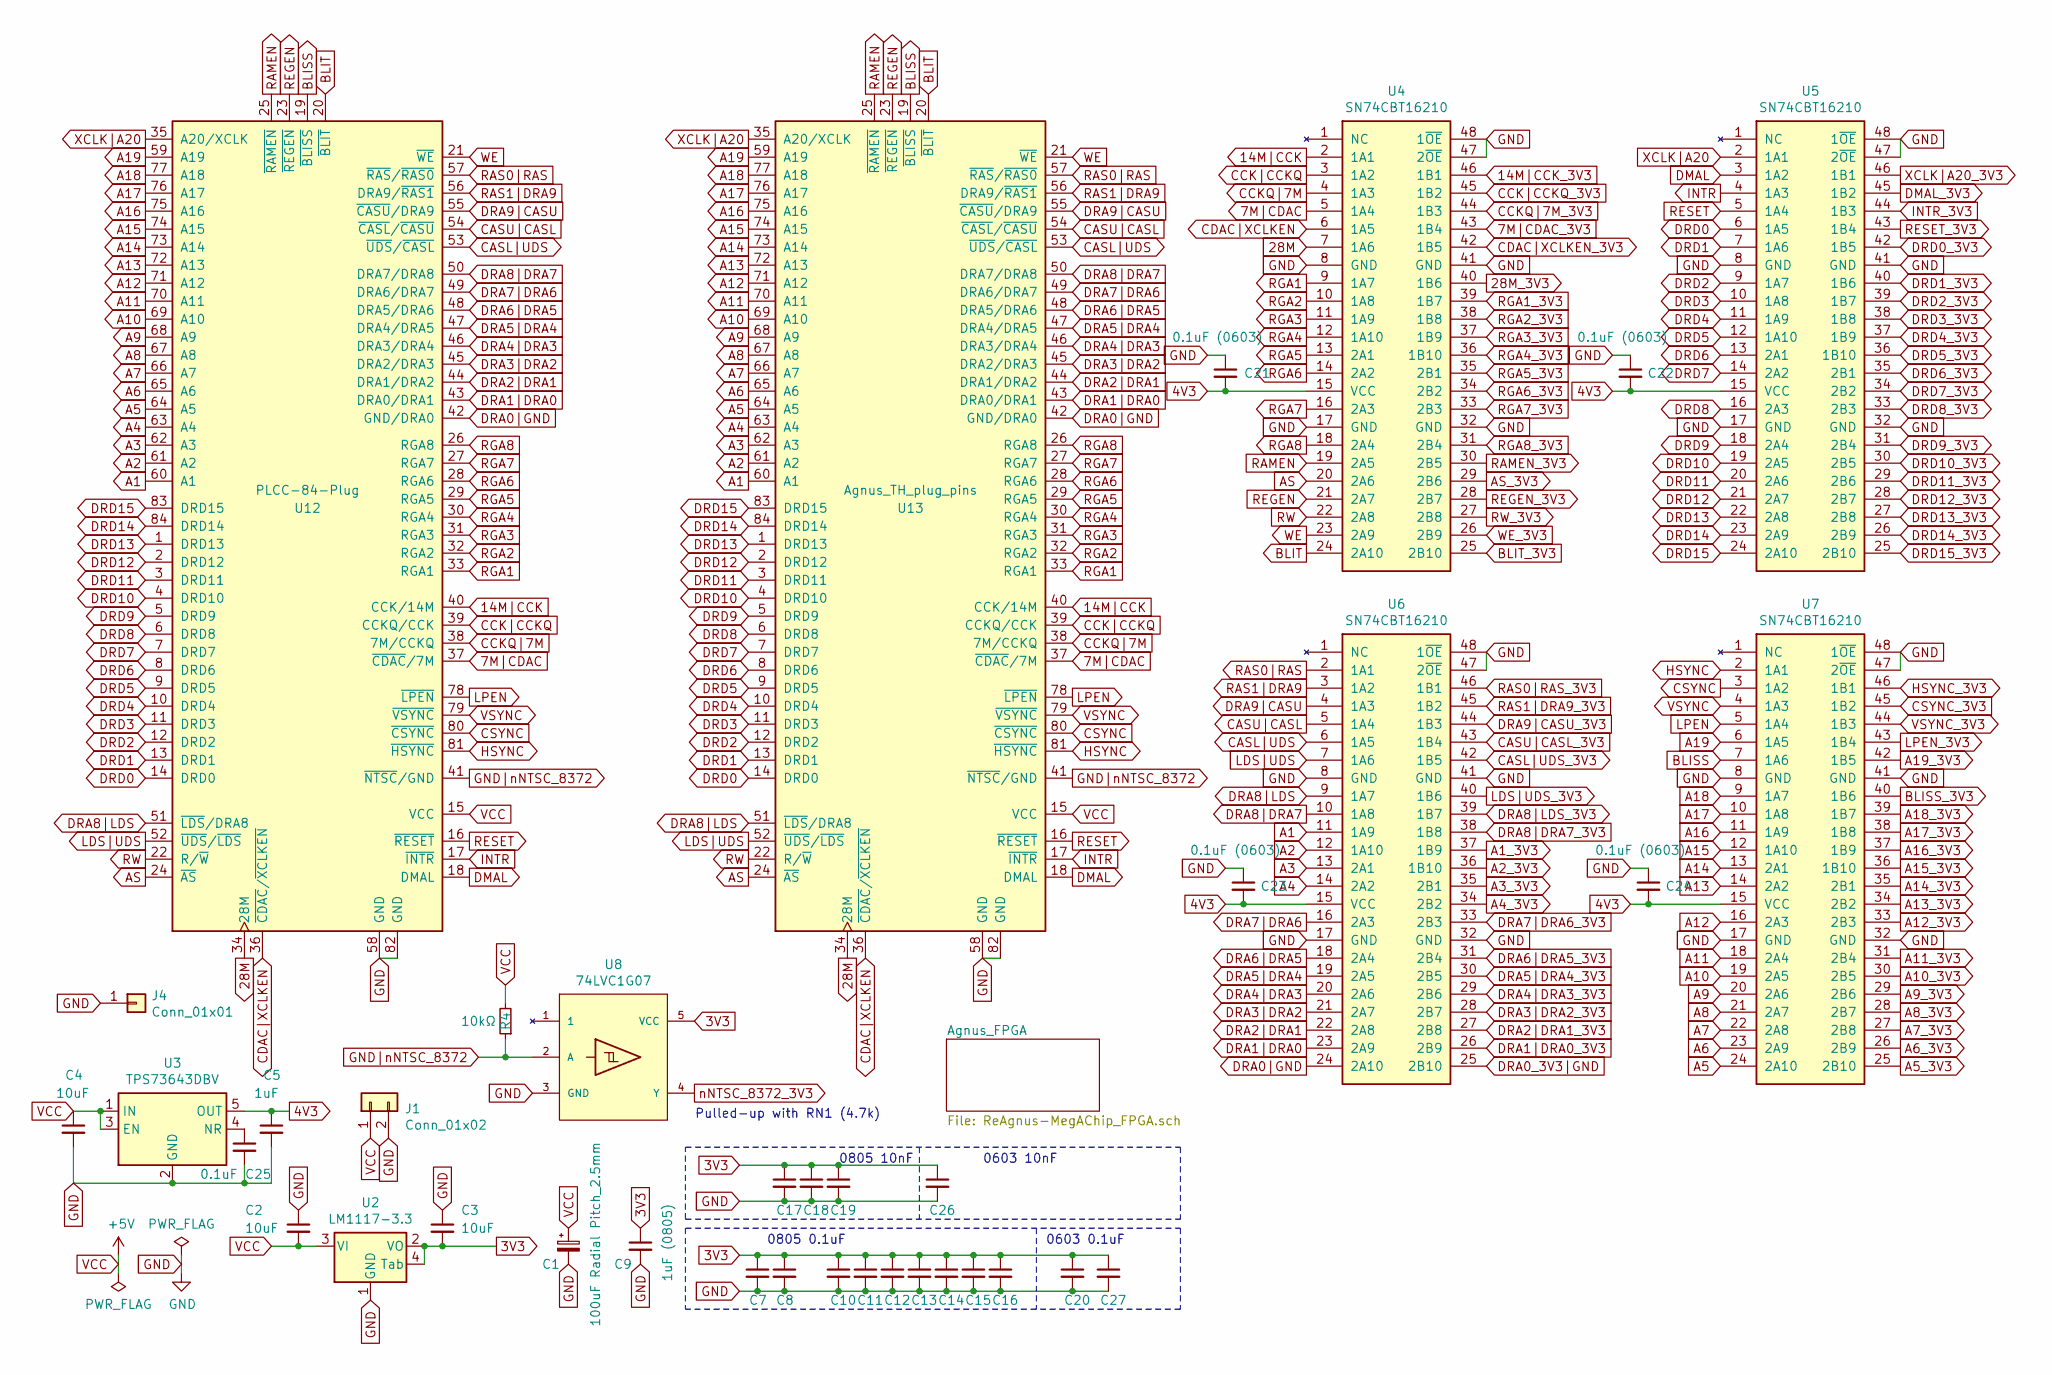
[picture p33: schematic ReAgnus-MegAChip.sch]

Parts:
C1: 100uF Radial Pitch_2.5mm; CP_Radial_D5.0mm_P2.50mm
C2, C3: 10uF; C_1206_3216Metric_Pad1.42x1.75mm_HandSolder
C4: 10uF; C_1206_3216Metric_Pad1.33x1.80mm_HandSolder
C5: 1uF; C_0805_2012Metric_Pad1.18x1.45mm_HandSolder
C7, C8, C10, C11, C12, C13, C14, C15, C16: 0.1uF; C_0805_2012Metric_Pad1.15x1.40mm_HandSolder
C9: 1uF (0805); C_0805_2012Metric_Pad1.15x1.40mm_HandSolder
C17, C18, C19: 0.01uF; C_0805_2012Metric_Pad1.15x1.40mm_HandSolder
C20, C26: 0.01uF; C_0603_1608Metric_Pad1.05x0.95mm_HandSolder
C21, C22, C23, C24: 0.1uF (0603); C_0603_1608Metric_Pad1.05x0.95mm_HandSolder
C25, C27: 0.1uF; C_0603_1608Metric_Pad1.08x0.95mm_HandSolder
J1: Conn_01x02; PinHeader_1x02_P2.54mm_Vertical
J4: Conn_01x01; MountingHole_2.2mm_M2_Pad_Via
R4: 10kΩ; R_0603_1608Metric_Pad0.98x0.95mm_HandSolder
U2: LM1117-3.3; SOT-223
U3: TPS73643DBV; SOT-23-5
U4, U5, U6, U7: SN74CBT16210; TSSOP-48_4.4x9.7mm_P0.4mm
U8: 74LVC1G07; SOT-353_SC-70-5_Custom_Handsoldering
U12: PLCC-84-Plug; PLCC-84_Plug_P1.27mm_mirrored
U13: Agnus_TH_plug_pins; PLCC-84_TH_pin_holes

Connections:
3V3: C3.2, C7.1, C8.1, C9.1, C10.1, C11.1, C12.1, C13.1, C14.1, C15.1, C16.1, C17.1, C18.1, C19.1, C20.1, C26.1, C27.1, U2.2 (VO), U2.4 (Tab), U8.5 (VCC); also elsewhere on the board
4V3: C5.1, C21.2, C22.2, C23.2, C24.2, U3.5 (OUT), U4.15 (VCC), U5.15 (VCC), U6.15 (VCC), U7.15 (VCC)
7M|CDAC: U4.5 (1A4), U12.37 (~CDAC~/7M), U13.37 (~CDAC~/7M)
7M|CDAC_3V3: U4.43 (1B4); also elsewhere on the board
14M|CCK: U4.2 (1A1), U12.40 (CCK/14M), U13.40 (CCK/14M)
14M|CCK_3V3: U4.46 (1B1); also elsewhere on the board
28M: U4.7 (1A6), U12.34 (28M), U13.34 (28M)
28M_3V3: U4.40 (1B6); also elsewhere on the board
A1: U6.11 (1A9), U12.60 (A1), U13.60 (A1)
A1_3V3: U6.37 (1B9); also elsewhere on the board
A2: U6.12 (1A10), U12.61 (A2), U13.61 (A2)
A2_3V3: U6.36 (1B10); also elsewhere on the board
A3: U6.13 (2A1), U12.62 (A3), U13.62 (A3)
A3_3V3: U6.35 (2B1); also elsewhere on the board
A4: U6.14 (2A2), U12.63 (A4), U13.63 (A4)
A4_3V3: U6.34 (2B2); also elsewhere on the board
A5: U7.24 (2A10), U12.64 (A5), U13.64 (A5)
A5_3V3: U7.25 (2B10); also elsewhere on the board
A6: U7.23 (2A9), U12.65 (A6), U13.65 (A6)
A6_3V3: U7.26 (2B9); also elsewhere on the board
A7: U7.22 (2A8), U12.66 (A7), U13.66 (A7)
A7_3V3: U7.27 (2B8); also elsewhere on the board
A8: U7.21 (2A7), U12.67 (A8), U13.67 (A8)
A8_3V3: U7.28 (2B7); also elsewhere on the board
A9: U7.20 (2A6), U12.68 (A9), U13.68 (A9)
A9_3V3: U7.29 (2B6); also elsewhere on the board
A10: U7.19 (2A5), U12.69 (A10), U13.69 (A10)
A10_3V3: U7.30 (2B5); also elsewhere on the board
A11: U7.18 (2A4), U12.70 (A11), U13.70 (A11)
A11_3V3: U7.31 (2B4); also elsewhere on the board
A12: U7.16 (2A3), U12.71 (A12), U13.71 (A12)
A12_3V3: U7.33 (2B3); also elsewhere on the board
A13: U7.14 (2A2), U12.72 (A13), U13.72 (A13)
A13_3V3: U7.34 (2B2); also elsewhere on the board
A14: U7.13 (2A1), U12.73 (A14), U13.73 (A14)
A14_3V3: U7.35 (2B1); also elsewhere on the board
A15: U7.12 (1A10), U12.74 (A15), U13.74 (A15)
A15_3V3: U7.36 (1B10); also elsewhere on the board
A16: U7.11 (1A9), U12.75 (A16), U13.75 (A16)
A16_3V3: U7.37 (1B9); also elsewhere on the board
A17: U7.10 (1A8), U12.76 (A17), U13.76 (A17)
A17_3V3: U7.38 (1B8); also elsewhere on the board
A18: U7.9 (1A7), U12.77 (A18), U13.77 (A18)
A18_3V3: U7.39 (1B7); also elsewhere on the board
A19: U7.6 (1A5), U12.59 (A19), U13.59 (A19)
A19_3V3: U7.42 (1B5); also elsewhere on the board
AS: U4.20 (2A6), U12.24 (~AS), U13.24 (~AS)
AS_3V3: U4.29 (2B6); also elsewhere on the board
BLISS: U7.7 (1A6), U12.19 (~BLISS), U13.19 (~BLISS)
BLISS_3V3: U7.40 (1B6); also elsewhere on the board
BLIT: U4.24 (2A10), U12.20 (~BLIT), U13.20 (~BLIT)
BLIT_3V3: U4.25 (2B10); also elsewhere on the board
CASL|UDS: U6.6 (1A5), U12.53 (~UDS~/~CASL), U13.53 (~UDS~/~CASL)
CASL|UDS_3V3: U6.42 (1B5); also elsewhere on the board
CASU|CASL: U6.5 (1A4), U12.54 (~CASL~/~CASU), U13.54 (~CASL~/~CASU)
CASU|CASL_3V3: U6.43 (1B4); also elsewhere on the board
CCKQ|7M: U4.4 (1A3), U12.38 (7M/CCKQ), U13.38 (7M/CCKQ)
CCKQ|7M_3V3: U4.44 (1B3); also elsewhere on the board
CCK|CCKQ: U4.3 (1A2), U12.39 (CCKQ/CCK), U13.39 (CCKQ/CCK)
CCK|CCKQ_3V3: U4.45 (1B2); also elsewhere on the board
CDAC|XCLKEN: U4.6 (1A5), U12.36 (~CDAC~/~XCLKEN), U13.36 (~CDAC~/~XCLKEN)
CDAC|XCLKEN_3V3: U4.42 (1B5); also elsewhere on the board
CSYNC: U7.3 (1A2), U12.80 (~CSYNC), U13.80 (~CSYNC)
CSYNC_3V3: U7.45 (1B2); also elsewhere on the board
DMAL: U5.3 (1A2), U12.18 (DMAL), U13.18 (DMAL)
DMAL_3V3: U5.45 (1B2); also elsewhere on the board
DRA0_3V3|GND: U6.25 (2B10); also elsewhere on the board
DRA0|GND: U6.24 (2A10), U12.42 (GND/DRA0), U13.42 (GND/DRA0)
DRA1|DRA0: U6.23 (2A9), U12.43 (DRA0/DRA1), U13.43 (DRA0/DRA1)
DRA1|DRA0_3V3: U6.26 (2B9); also elsewhere on the board
DRA2|DRA1: U6.22 (2A8), U12.44 (DRA1/DRA2), U13.44 (DRA1/DRA2)
DRA2|DRA1_3V3: U6.27 (2B8); also elsewhere on the board
DRA3|DRA2: U6.21 (2A7), U12.45 (DRA2/DRA3), U13.45 (DRA2/DRA3)
DRA3|DRA2_3V3: U6.28 (2B7); also elsewhere on the board
DRA4|DRA3: U6.20 (2A6), U12.46 (DRA3/DRA4), U13.46 (DRA3/DRA4)
DRA4|DRA3_3V3: U6.29 (2B6); also elsewhere on the board
DRA5|DRA4: U6.19 (2A5), U12.47 (DRA4/DRA5), U13.47 (DRA4/DRA5)
DRA5|DRA4_3V3: U6.30 (2B5); also elsewhere on the board
DRA6|DRA5: U6.18 (2A4), U12.48 (DRA5/DRA6), U13.48 (DRA5/DRA6)
DRA6|DRA5_3V3: U6.31 (2B4); also elsewhere on the board
DRA7|DRA6: U6.16 (2A3), U12.49 (DRA6/DRA7), U13.49 (DRA6/DRA7)
DRA7|DRA6_3V3: U6.33 (2B3); also elsewhere on the board
DRA8|DRA7: U6.10 (1A8), U12.50 (DRA7/DRA8), U13.50 (DRA7/DRA8)
DRA8|DRA7_3V3: U6.38 (1B8); also elsewhere on the board
DRA8|LDS: U6.9 (1A7), U12.51 (~LDS~/DRA8), U13.51 (~LDS~/DRA8)
DRA8|LDS_3V3: U6.39 (1B7); also elsewhere on the board
DRA9|CASU: U6.4 (1A3), U12.55 (~CASU~/DRA9), U13.55 (~CASU~/DRA9)
DRA9|CASU_3V3: U6.44 (1B3); also elsewhere on the board
DRD0: U5.6 (1A5), U12.14 (DRD0), U13.14 (DRD0)
DRD0_3V3: U5.42 (1B5); also elsewhere on the board
DRD1: U5.7 (1A6), U12.13 (DRD1), U13.13 (DRD1)
DRD1_3V3: U5.40 (1B6); also elsewhere on the board
DRD2: U5.9 (1A7), U12.12 (DRD2), U13.12 (DRD2)
DRD2_3V3: U5.39 (1B7); also elsewhere on the board
DRD3: U5.10 (1A8), U12.11 (DRD3), U13.11 (DRD3)
DRD3_3V3: U5.38 (1B8); also elsewhere on the board
DRD4: U5.11 (1A9), U12.10 (DRD4), U13.10 (DRD4)
DRD4_3V3: U5.37 (1B9); also elsewhere on the board
DRD5: U5.12 (1A10), U12.9 (DRD5), U13.9 (DRD5)
DRD5_3V3: U5.36 (1B10); also elsewhere on the board
DRD6: U5.13 (2A1), U12.8 (DRD6), U13.8 (DRD6)
DRD6_3V3: U5.35 (2B1); also elsewhere on the board
DRD7: U5.14 (2A2), U12.7 (DRD7), U13.7 (DRD7)
DRD7_3V3: U5.34 (2B2); also elsewhere on the board
DRD8: U5.16 (2A3), U12.6 (DRD8), U13.6 (DRD8)
DRD8_3V3: U5.33 (2B3); also elsewhere on the board
DRD9: U5.18 (2A4), U12.5 (DRD9), U13.5 (DRD9)
DRD9_3V3: U5.31 (2B4); also elsewhere on the board
DRD10: U5.19 (2A5), U12.4 (DRD10), U13.4 (DRD10)
DRD10_3V3: U5.30 (2B5); also elsewhere on the board
DRD11: U5.20 (2A6), U12.3 (DRD11), U13.3 (DRD11)
DRD11_3V3: U5.29 (2B6); also elsewhere on the board
DRD12: U5.21 (2A7), U12.2 (DRD12), U13.2 (DRD12)
DRD12_3V3: U5.28 (2B7); also elsewhere on the board
DRD13: U5.22 (2A8), U12.1 (DRD13), U13.1 (DRD13)
DRD13_3V3: U5.27 (2B8); also elsewhere on the board
DRD14: U5.23 (2A9), U12.84 (DRD14), U13.84 (DRD14)
DRD14_3V3: U5.26 (2B9); also elsewhere on the board
DRD15: U5.24 (2A10), U12.83 (DRD15), U13.83 (DRD15)
DRD15_3V3: U5.25 (2B10); also elsewhere on the board
GND: C1.2, C2.1, C3.1, C4.2, C5.2, C7.2, C8.2, C9.2, C10.2, C11.2, C12.2, C13.2, C14.2, C15.2, C16.2, C17.2, C18.2, C19.2, C20.2, C21.1, C22.1, C23.1, C24.1, C25.2, C26.2, C27.2, J1.2, J4.1, U2.1 (GND), U3.2 (GND), U4.8 (GND), U4.17 (GND), U4.32 (GND), U4.41 (GND), U4.47 (2~OE), U4.48 (1~OE), U5.8 (GND), U5.17 (GND), U5.32 (GND), U5.41 (GND), U5.47 (2~OE), U5.48 (1~OE), U6.8 (GND), U6.17 (GND), U6.32 (GND), U6.41 (GND), U6.47 (2~OE), U6.48 (1~OE), U7.8 (GND), U7.17 (GND), U7.32 (GND), U7.41 (GND), U7.47 (2~OE), U7.48 (1~OE), U8.3 (GND), U12.58 (GND), U12.82 (GND), U13.58 (GND), U13.82 (GND); also elsewhere on the board
GND|nNTSC_8372: R4.1, U8.2 (A), U12.41 (~NTSC~/GND), U13.41 (~NTSC~/GND)
HSYNC: U7.2 (1A1), U12.81 (~HSYNC), U13.81 (~HSYNC)
HSYNC_3V3: U7.46 (1B1); also elsewhere on the board
INTR: U5.4 (1A3), U12.17 (~INTR), U13.17 (~INTR)
INTR_3V3: U5.44 (1B3); also elsewhere on the board
LDS|UDS: U6.7 (1A6), U12.52 (~UDS~/~LDS~), U13.52 (~UDS~/~LDS~)
LDS|UDS_3V3: U6.40 (1B6); also elsewhere on the board
LPEN: U7.5 (1A4), U12.78 (~LPEN), U13.78 (~LPEN)
LPEN_3V3: U7.43 (1B4); also elsewhere on the board
unnamed: C25.1, U3.4 (NR)
RAMEN: U4.19 (2A5), U12.25 (~RAMEN), U13.25 (~RAMEN)
RAMEN_3V3: U4.30 (2B5); also elsewhere on the board
RAS0|RAS: U6.2 (1A1), U12.57 (~RAS~/~RAS0), U13.57 (~RAS~/~RAS0)
RAS0|RAS_3V3: U6.46 (1B1); also elsewhere on the board
RAS1|DRA9: U6.3 (1A2), U12.56 (DRA9/~RAS1), U13.56 (DRA9/~RAS1)
RAS1|DRA9_3V3: U6.45 (1B2); also elsewhere on the board
REGEN: U4.21 (2A7), U12.23 (~REGEN), U13.23 (~REGEN)
REGEN_3V3: U4.28 (2B7); also elsewhere on the board
RESET: U5.5 (1A4), U12.16 (~RESET), U13.16 (~RESET)
RESET_3V3: U5.43 (1B4); also elsewhere on the board
RGA1: U4.9 (1A7), U12.33 (RGA1), U13.33 (RGA1)
RGA1_3V3: U4.39 (1B7); also elsewhere on the board
RGA2: U4.10 (1A8), U12.32 (RGA2), U13.32 (RGA2)
RGA2_3V3: U4.38 (1B8); also elsewhere on the board
RGA3: U4.11 (1A9), U12.31 (RGA3), U13.31 (RGA3)
RGA3_3V3: U4.37 (1B9); also elsewhere on the board
RGA4: U4.12 (1A10), U12.30 (RGA4), U13.30 (RGA4)
RGA4_3V3: U4.36 (1B10); also elsewhere on the board
RGA5: U4.13 (2A1), U12.29 (RGA5), U13.29 (RGA5)
RGA5_3V3: U4.35 (2B1); also elsewhere on the board
RGA6: U4.14 (2A2), U12.28 (RGA6), U13.28 (RGA6)
RGA6_3V3: U4.34 (2B2); also elsewhere on the board
RGA7: U4.16 (2A3), U12.27 (RGA7), U13.27 (RGA7)
RGA7_3V3: U4.33 (2B3); also elsewhere on the board
RGA8: U4.18 (2A4), U12.26 (RGA8), U13.26 (RGA8)
RGA8_3V3: U4.31 (2B4); also elsewhere on the board
RW: U4.22 (2A8), U12.22 (R/~W), U13.22 (R/~W)
RW_3V3: U4.27 (2B8); also elsewhere on the board
VCC: C1.1, C2.2, C4.1, J1.1, R4.2, U2.3 (VI), U3.1 (IN), U3.3 (EN), U12.15 (VCC), U13.15 (VCC)
VSYNC: U7.4 (1A3), U12.79 (~VSYNC), U13.79 (~VSYNC)
VSYNC_3V3: U7.44 (1B3); also elsewhere on the board
WE: U4.23 (2A9), U12.21 (~WE), U13.21 (~WE)
WE_3V3: U4.26 (2B9); also elsewhere on the board
XCLK|A20: U5.2 (1A1), U12.35 (A20/XCLK), U13.35 (A20/XCLK)
XCLK|A20_3V3: U5.46 (1B1); also elsewhere on the board
nNTSC_8372_3V3: U8.4 (Y); also elsewhere on the board

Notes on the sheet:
Pulled-up with RN1 (4.7k)
0805 10nF
0805 0.1uF
0603 10nF
0603 0.1uF

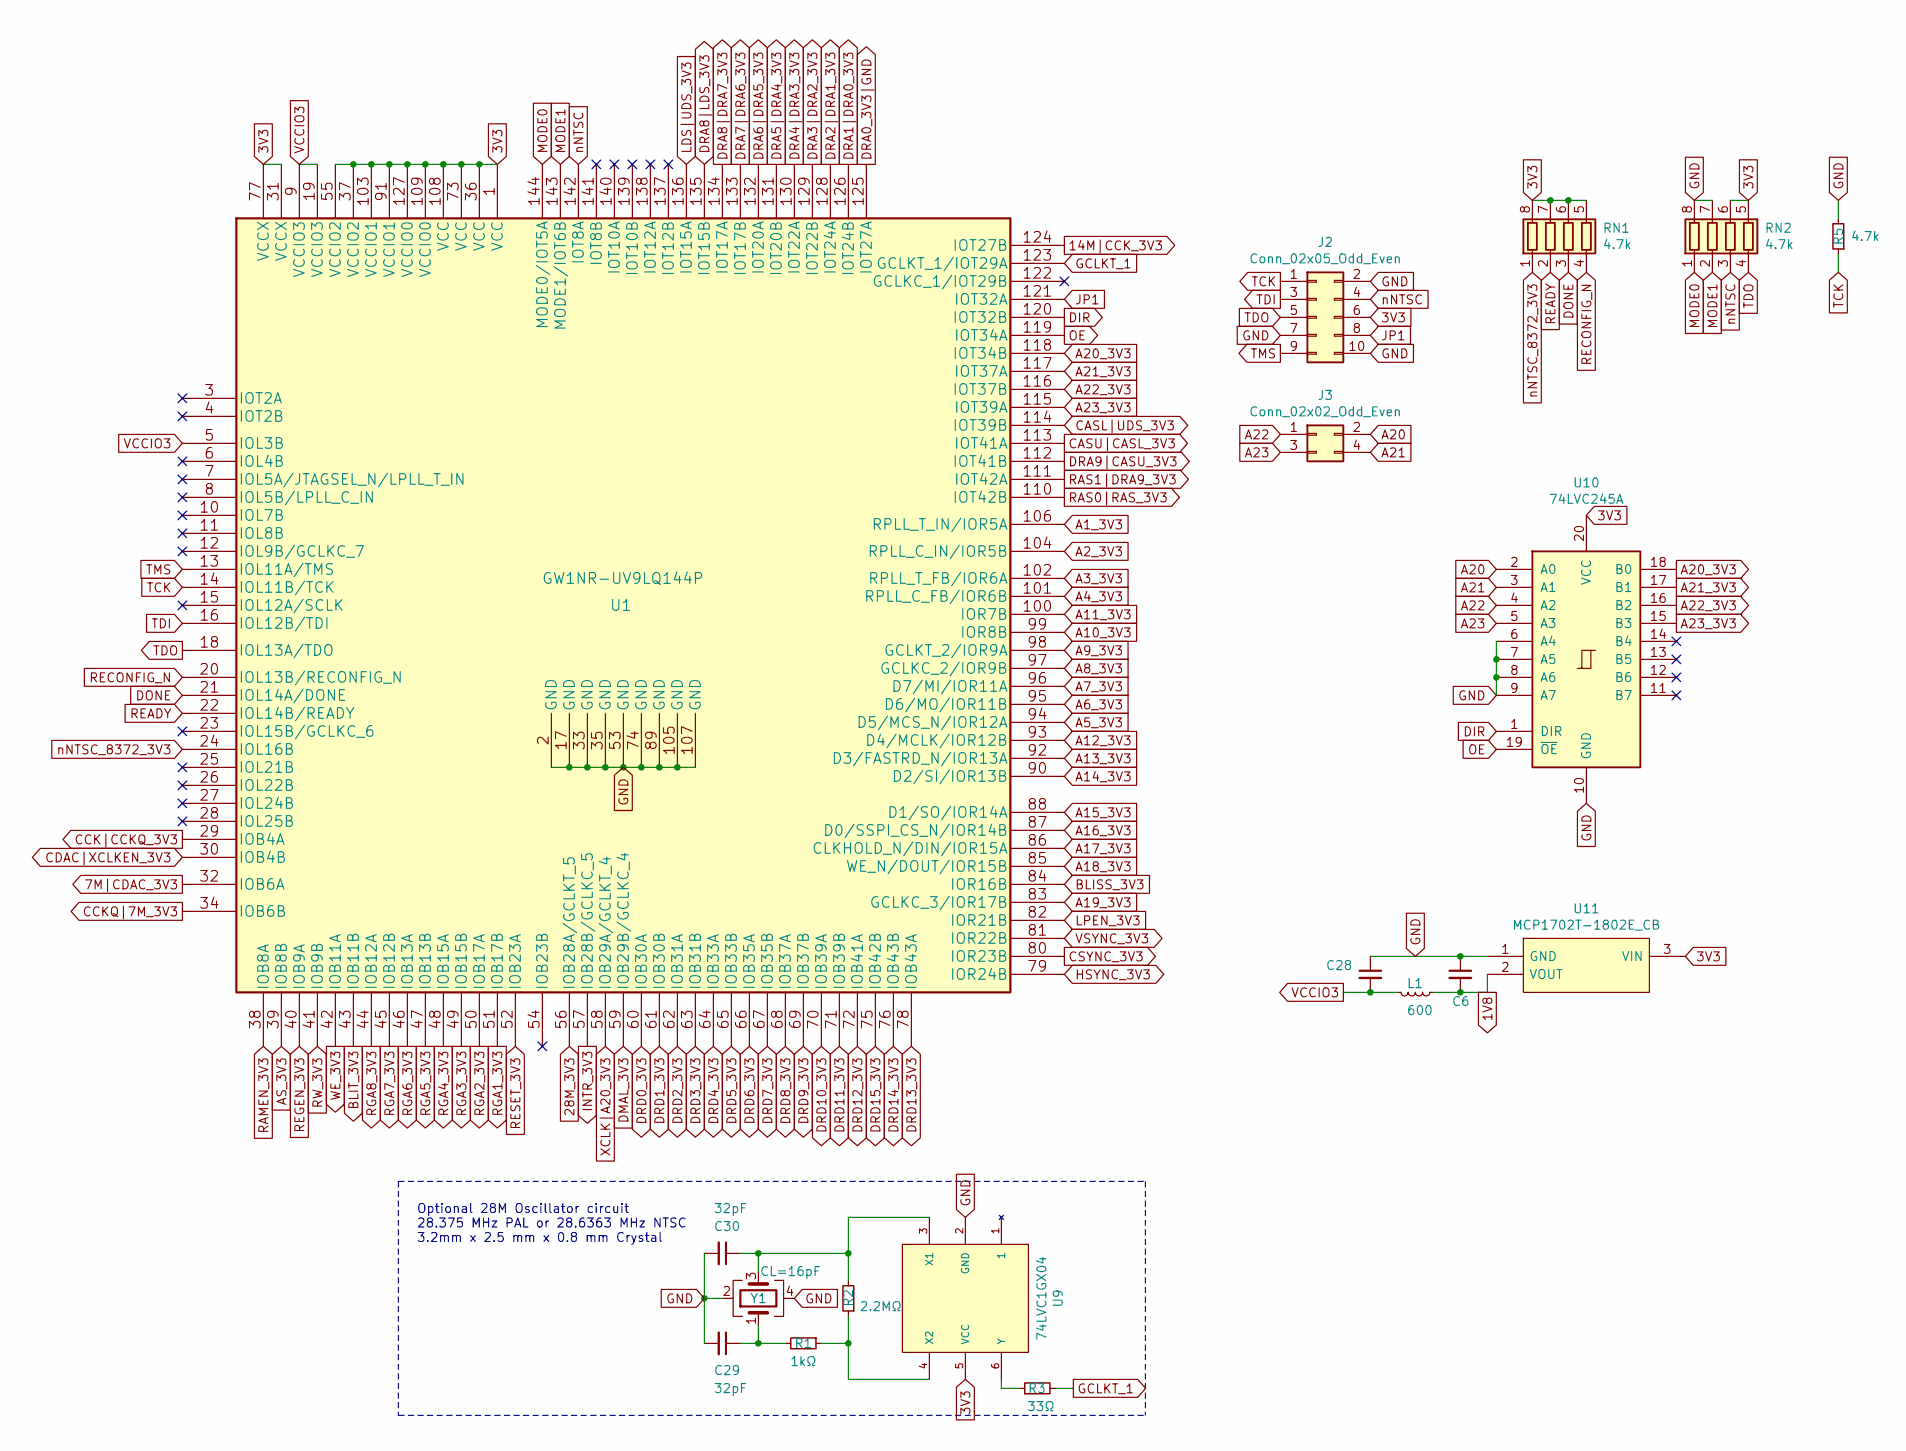
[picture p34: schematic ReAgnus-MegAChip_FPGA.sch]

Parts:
C6: 10uF; C_0805_2012Metric_Pad1.18x1.45mm_HandSolder
C28: 0.1uF; C_0603_1608Metric_Pad1.08x0.95mm_HandSolder
C29, C30: 32pF; C_0603_1608Metric_Pad1.05x0.95mm_HandSolder
J2: Conn_02x05_Odd_Even; PinHeader_2x05_P2.54mm_Vertical
J3: Conn_02x02_Odd_Even; PinHeader_2x02_P2.00mm_Vertical
L1: 600; L_0805_2012Metric_Pad1.05x1.20mm_HandSolder
R1: 1kΩ; R_0603_1608Metric_Pad1.05x0.95mm_HandSolder
R2: 2.2MΩ; R_0603_1608Metric_Pad1.05x0.95mm_HandSolder
R3: 33Ω; R_0603_1608Metric_Pad0.98x0.95mm_HandSolder
R5: 4.7k; R_0603_1608Metric_Pad0.98x0.95mm_HandSolder
RN1, RN2: 4.7k; RESCAF80P320X160X60-8N
U1: GW1NR-UV9LQ144P; LQFP-144_20x20mm_P0.5mm
U9: 74LVC1GX04; TSOP-6_1.65x3.05mm_P0.95mm
U10: 74LVC245A; TSSOP-20_4.4x6.5mm_P0.65mm
U11: MCP1702T-1802E_CB; SOT-23_Handsoldering
Y1: CL=16pF; Crystal_SMD_SeikoEpson_FA238-4Pin_3.2x2.5mm

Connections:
1V8: C6.2, L1.1, U11.2 (VOUT)
3V3: J2.6, RN1.5 (R4.2), RN1.6 (R3.2), RN1.7 (R2.2), RN1.8 (R1.2), RN2.5 (R4.2), RN2.6 (R3.2), U1.1 (VCC), U1.31 (VCCX), U1.36 (VCC), U1.37 (VCCIO2), U1.55 (VCCIO2), U1.73 (VCC), U1.77 (VCCX), U1.91 (VCCIO1), U1.103 (VCCIO1), U1.108 (VCC), U1.109 (VCCIO0), U1.127 (VCCIO0), U9.5 (VCC), U10.20 (VCC), U11.3 (VIN); also elsewhere on the board
7M|CDAC_3V3: U1.32 (IOB6A); also elsewhere on the board
14M|CCK_3V3: U1.124 (IOT27B); also elsewhere on the board
28M_3V3: U1.56 (IOB28A/GCLKT_5); also elsewhere on the board
A1_3V3: U1.106 (RPLL_T_IN/IOR5A); also elsewhere on the board
A2_3V3: U1.104 (RPLL_C_IN/IOR5B); also elsewhere on the board
A3_3V3: U1.102 (RPLL_T_FB/IOR6A); also elsewhere on the board
A4_3V3: U1.101 (RPLL_C_FB/IOR6B); also elsewhere on the board
A5_3V3: U1.94 (D5/MCS_N/IOR12A); also elsewhere on the board
A6_3V3: U1.95 (D6/MO/IOR11B); also elsewhere on the board
A7_3V3: U1.96 (D7/MI/IOR11A); also elsewhere on the board
A8_3V3: U1.97 (GCLKC_2/IOR9B); also elsewhere on the board
A9_3V3: U1.98 (GCLKT_2/IOR9A); also elsewhere on the board
A10_3V3: U1.99 (IOR8B); also elsewhere on the board
A11_3V3: U1.100 (IOR7B); also elsewhere on the board
A12_3V3: U1.93 (D4/MCLK/IOR12B); also elsewhere on the board
A13_3V3: U1.92 (D3/FASTRD_N/IOR13A); also elsewhere on the board
A14_3V3: U1.90 (D2/SI/IOR13B); also elsewhere on the board
A15_3V3: U1.88 (D1/SO/IOR14A); also elsewhere on the board
A16_3V3: U1.87 (D0/SSPI_CS_N/IOR14B); also elsewhere on the board
A17_3V3: U1.86 (CLKHOLD_N/DIN/IOR15A); also elsewhere on the board
A18_3V3: U1.85 (WE_N/DOUT/IOR15B); also elsewhere on the board
A19_3V3: U1.83 (GCLKC_3/IOR17B); also elsewhere on the board
A20: J3.2, U10.2 (A0)
A20_3V3: U1.118 (IOT34B), U10.18 (B0)
A21: J3.4, U10.3 (A1)
A21_3V3: U1.117 (IOT37A), U10.17 (B1)
A22: J3.1, U10.4 (A2)
A22_3V3: U1.116 (IOT37B), U10.16 (B2)
A23: J3.3, U10.5 (A3)
A23_3V3: U1.115 (IOT39A), U10.15 (B3)
AS_3V3: U1.39 (IOB8B); also elsewhere on the board
BLISS_3V3: U1.84 (IOR16B); also elsewhere on the board
BLIT_3V3: U1.43 (IOB11B); also elsewhere on the board
CASL|UDS_3V3: U1.114 (IOT39B); also elsewhere on the board
CASU|CASL_3V3: U1.113 (IOT41A); also elsewhere on the board
CCKQ|7M_3V3: U1.34 (IOB6B); also elsewhere on the board
CCK|CCKQ_3V3: U1.29 (IOB4A); also elsewhere on the board
CDAC|XCLKEN_3V3: U1.30 (IOB4B); also elsewhere on the board
CSYNC_3V3: U1.80 (IOR23B); also elsewhere on the board
DIR: U1.120 (IOT32B), U10.1 (DIR)
DMAL_3V3: U1.59 (IOB29B/GCLKC_4); also elsewhere on the board
DONE: RN1.3 (R3.1), U1.21 (IOL14A/DONE)
DRA0_3V3|GND: U1.125 (IOT27A); also elsewhere on the board
DRA1|DRA0_3V3: U1.126 (IOT24B); also elsewhere on the board
DRA2|DRA1_3V3: U1.128 (IOT24A); also elsewhere on the board
DRA3|DRA2_3V3: U1.129 (IOT22B); also elsewhere on the board
DRA4|DRA3_3V3: U1.130 (IOT22A); also elsewhere on the board
DRA5|DRA4_3V3: U1.131 (IOT20B); also elsewhere on the board
DRA6|DRA5_3V3: U1.132 (IOT20A); also elsewhere on the board
DRA7|DRA6_3V3: U1.133 (IOT17B); also elsewhere on the board
DRA8|DRA7_3V3: U1.134 (IOT17A); also elsewhere on the board
DRA8|LDS_3V3: U1.135 (IOT15B); also elsewhere on the board
DRA9|CASU_3V3: U1.112 (IOT41B); also elsewhere on the board
DRD0_3V3: U1.60 (IOB30A); also elsewhere on the board
DRD1_3V3: U1.61 (IOB30B); also elsewhere on the board
DRD2_3V3: U1.62 (IOB31A); also elsewhere on the board
DRD3_3V3: U1.63 (IOB31B); also elsewhere on the board
DRD4_3V3: U1.64 (IOB33A); also elsewhere on the board
DRD5_3V3: U1.65 (IOB33B); also elsewhere on the board
DRD6_3V3: U1.66 (IOB35A); also elsewhere on the board
DRD7_3V3: U1.67 (IOB35B); also elsewhere on the board
DRD8_3V3: U1.68 (IOB37A); also elsewhere on the board
DRD9_3V3: U1.69 (IOB37B); also elsewhere on the board
DRD10_3V3: U1.70 (IOB39A); also elsewhere on the board
DRD11_3V3: U1.71 (IOB39B); also elsewhere on the board
DRD12_3V3: U1.72 (IOB41A); also elsewhere on the board
DRD13_3V3: U1.78 (IOB43A); also elsewhere on the board
DRD14_3V3: U1.76 (IOB43B); also elsewhere on the board
DRD15_3V3: U1.75 (IOB42B); also elsewhere on the board
GCLKT_1: R3.2, U1.123 (GCLKT_1/IOT29A)
GND: C6.1, C28.1, C29.2, C30.2, J2.2, J2.7, J2.10, R5.2, RN2.7 (R2.2), RN2.8 (R1.2), U1.2 (GND), U1.17 (GND), U1.33 (GND), U1.35 (GND), U1.53 (GND), U1.74 (GND), U1.89 (GND), U1.105 (GND), U1.107 (GND), U9.2 (GND), U10.6 (A4), U10.7 (A5), U10.8 (A6), U10.9 (A7), U10.10 (GND), U11.1 (GND), Y1.2, Y1.4; also elsewhere on the board
HSYNC_3V3: U1.79 (IOR24B); also elsewhere on the board
INTR_3V3: U1.57 (IOB28B/GCLKC_5); also elsewhere on the board
JP1: J2.8, U1.121 (IOT32A)
LDS|UDS_3V3: U1.136 (IOT15A); also elsewhere on the board
LPEN_3V3: U1.82 (IOR21B); also elsewhere on the board
MODE0: RN2.1 (R1.1), U1.144 (MODE0/IOT5A)
MODE1: RN2.2 (R2.1), U1.143 (MODE1/IOT6B)
unnamed: C29.1, R1.2, Y1.1
unnamed: C30.1, R2.2, U9.3 (X1), Y1.3
unnamed: R1.1, R2.1, U9.4 (X2)
unnamed: R3.1, U9.6 (Y)
OE: U1.119 (IOT34A), U10.19 (~OE)
RAMEN_3V3: U1.38 (IOB8A); also elsewhere on the board
RAS0|RAS_3V3: U1.110 (IOT42B); also elsewhere on the board
RAS1|DRA9_3V3: U1.111 (IOT42A); also elsewhere on the board
READY: RN1.2 (R2.1), U1.22 (IOL14B/READY)
RECONFIG_N: RN1.4 (R4.1), U1.20 (IOL13B/RECONFIG_N)
REGEN_3V3: U1.40 (IOB9A); also elsewhere on the board
RESET_3V3: U1.52 (IOB23A); also elsewhere on the board
RGA1_3V3: U1.51 (IOB17B); also elsewhere on the board
RGA2_3V3: U1.50 (IOB17A); also elsewhere on the board
RGA3_3V3: U1.49 (IOB15B); also elsewhere on the board
RGA4_3V3: U1.48 (IOB15A); also elsewhere on the board
RGA5_3V3: U1.47 (IOB13B); also elsewhere on the board
RGA6_3V3: U1.46 (IOB13A); also elsewhere on the board
RGA7_3V3: U1.45 (IOB12B); also elsewhere on the board
RGA8_3V3: U1.44 (IOB12A); also elsewhere on the board
RW_3V3: U1.41 (IOB9B); also elsewhere on the board
TCK: J2.1, R5.1, U1.14 (IOL11B/TCK)
TDI: J2.3, U1.16 (IOL12B/TDI)
TDO: J2.5, RN2.4 (R4.1), U1.18 (IOL13A/TDO)
TMS: J2.9, U1.13 (IOL11A/TMS)
VCCIO3: C28.2, L1.2, U1.5 (IOL3B), U1.9 (VCCIO3), U1.19 (VCCIO3)
VSYNC_3V3: U1.81 (IOR22B); also elsewhere on the board
WE_3V3: U1.42 (IOB11A); also elsewhere on the board
XCLK|A20_3V3: U1.58 (IOB29A/GCLKT_4); also elsewhere on the board
nNTSC: J2.4, RN2.3 (R3.1), U1.142 (IOT8A)
nNTSC_8372_3V3: RN1.1 (R1.1), U1.24 (IOL16B); also elsewhere on the board

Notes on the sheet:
Optional 28M Oscillator circuit 28.375 MHz PAL or 28.6363 MHz NTSC 3.2mm x 2.5 mm x 0.8 mm Crystal

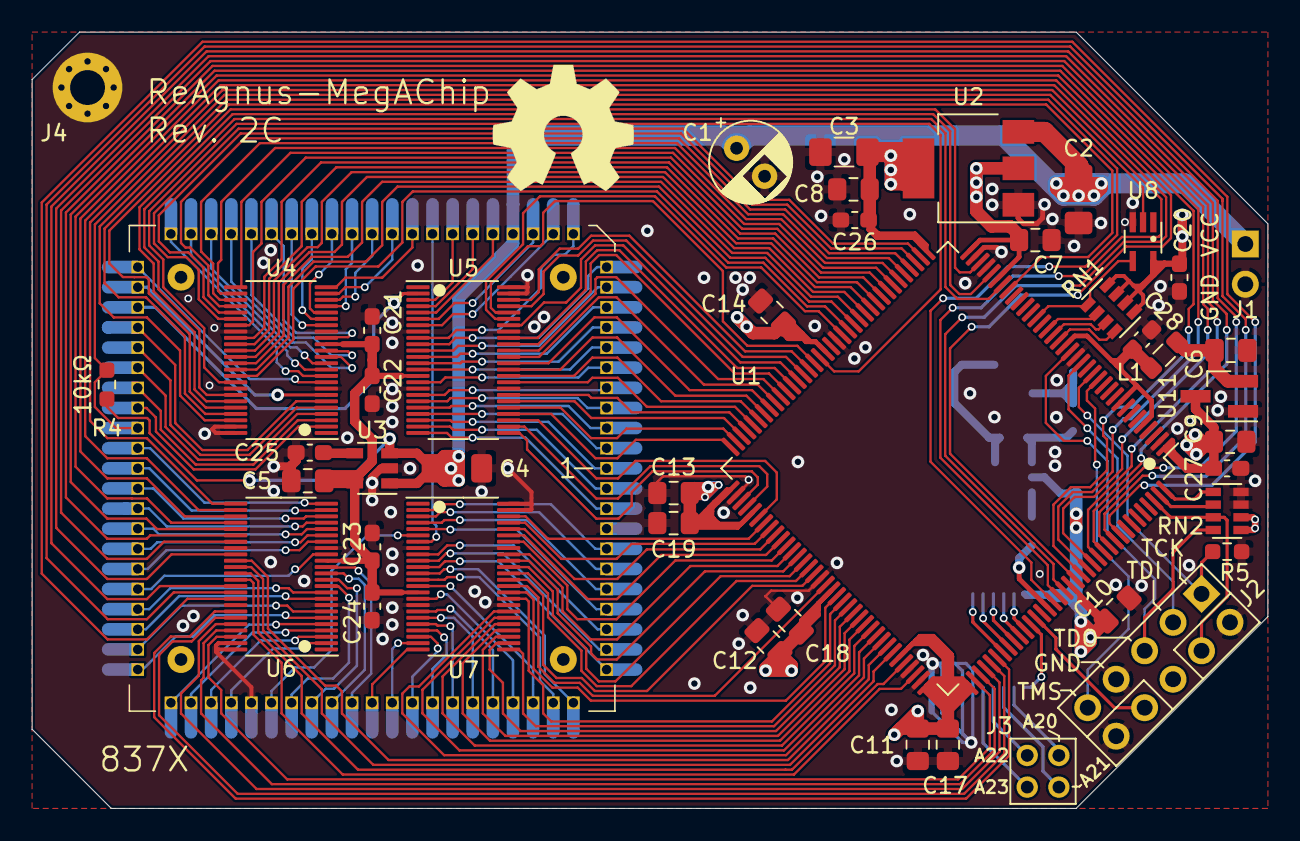
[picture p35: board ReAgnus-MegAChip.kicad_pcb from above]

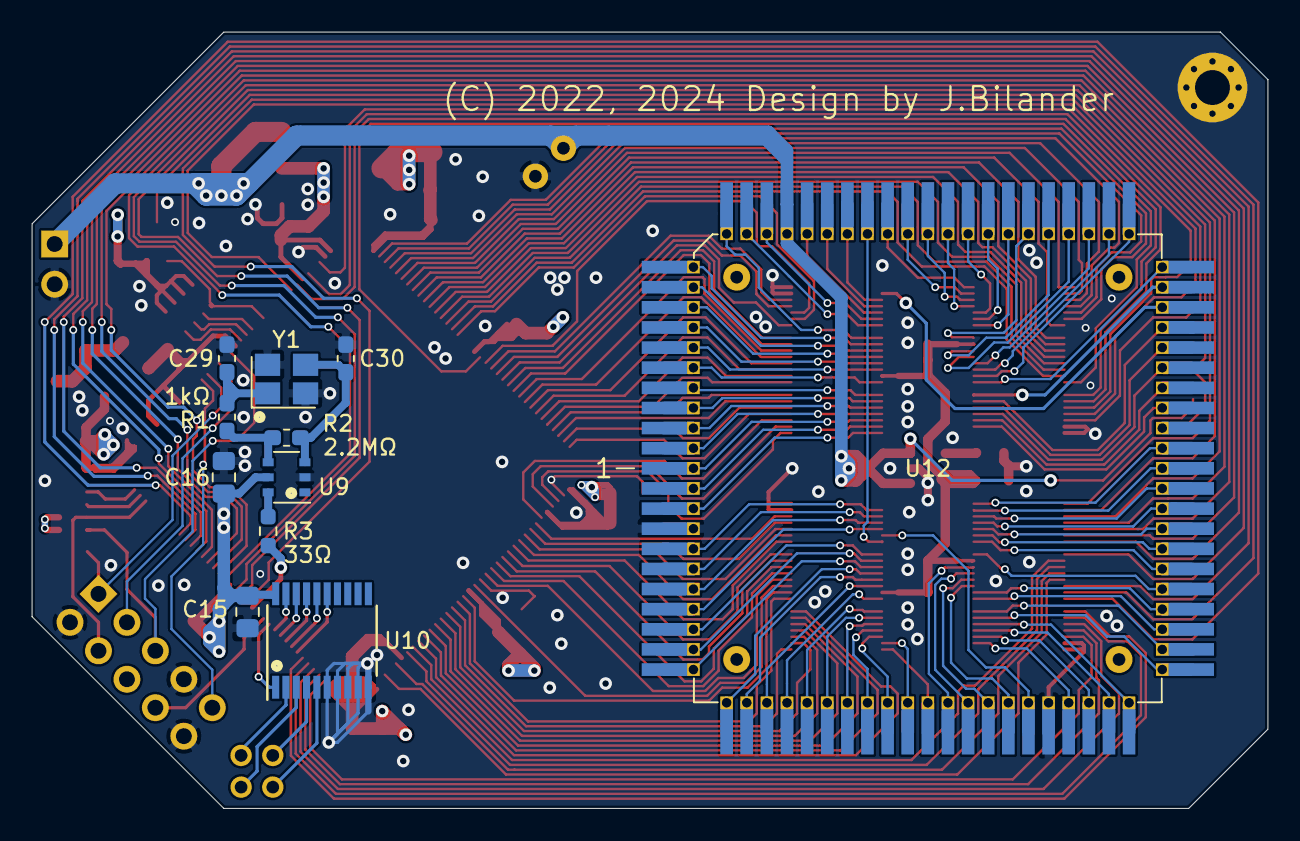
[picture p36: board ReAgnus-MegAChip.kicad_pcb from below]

Board: 4 copper layers, 78.0 x 49.0 mm, 56 parts (11 on the bottom side), 195 nets.

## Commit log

2022-08-22 added KiCAD files
    [ReAgnus-MegAChip.kicad_pcb, ReAgnus-MegAChip.sch]
2022-08-26 added FPGA schematic file
    [ReAgnus-MegAChip_FPGA.sch]
2022-08-26 more routing and placing components
    [ReAgnus-MegAChip.kicad_pcb, ReAgnus-MegAChip.sch]
2022-08-28 made custom footprint
2022-09-01 commit before PCB design change
    [ReAgnus-MegAChip.kicad_pcb]
2022-09-01 major redesign of PCB done
    [ReAgnus-MegAChip.kicad_pcb, ReAgnus-MegAChip.sch, ReAgnus-MegAChip_FPGA.sch]
2022-09-02 added footprint
2022-09-02 added 74LVC1G07 buffer with open-drain output
    [ReAgnus-MegAChip.kicad_pcb, ReAgnus-MegAChip.sch, ReAgnus-MegAChip_FPGA.sch]
2022-09-03 more routing
    [ReAgnus-MegAChip.kicad_pcb, ReAgnus-MegAChip.sch, ReAgnus-MegAChip_FPGA.sch]
2022-09-03 added pull-up resistors on PAL/NTSC-line, added JTAG-header
    [ReAgnus-MegAChip.kicad_pcb, ReAgnus-MegAChip.sch, ReAgnus-MegAChip_FPGA.sch]
2022-09-07 fixed routing for VCC to voltage regulator, placed two-pin header for VCC/GND and more routing
    [ReAgnus-MegAChip.kicad_pcb, ReAgnus-MegAChip.sch]
2022-09-08 added 3D step file for cay16-103j4lf resistor pack
2022-09-08 went to two layers, deleted inner layers GND and VCC
    [ReAgnus-MegAChip.kicad_pcb]
2022-09-09 renaming of Capacitors
    [ReAgnus-MegAChip.kicad_pcb, ReAgnus-MegAChip.sch, ReAgnus-MegAChip_FPGA.sch]
2022-09-14 added Oscillator X1 for SDRAM and GCLKT_1 pin on FPGA
    [ReAgnus-MegAChip.kicad_pcb, ReAgnus-MegAChip.sch, ReAgnus-MegAChip_FPGA.sch]
2022-09-15 added 74LVC245A IC for A20-A23 and more routing done
    [ReAgnus-MegAChip.kicad_pcb, ReAgnus-MegAChip_FPGA.sch]
2022-09-16 added 74LVC1GX04 X-tal driver
2022-09-17 corrected X2-pin to an output on 74LVC1GX04-symbol
2022-09-17 added optional Oscillator circuit with 28M crystal 3.2mm x 2.5mm x 0.8mm
    [ReAgnus-MegAChip.kicad_pcb, ReAgnus-MegAChip_FPGA.sch]
2022-09-22 silkscreen fixes
    [ReAgnus-MegAChip.kicad_pcb, ReAgnus-MegAChip_FPGA.sch]
2022-09-23 added decoupling cap for U11
    [ReAgnus-MegAChip.kicad_pcb, ReAgnus-MegAChip.sch]
2022-09-23 fixed power routing and decoupling caps for U10 (SDRAM)
    [ReAgnus-MegAChip.kicad_pcb, ReAgnus-MegAChip.sch]
2022-10-05 Added JP3 with pull-up resistor on FPGA-pin IOL5A to J3-jack and changed J3 from a two- to a three-pinHeader.
    [ReAgnus-MegAChip.kicad_pcb, ReAgnus-MegAChip.sch, ReAgnus-MegAChip_FPGA.sch]
2022-10-06 via-grounding and silkscreen fixes
    [ReAgnus-MegAChip.kicad_pcb]
2022-10-06 better grounding and silkscreen fixes on backside
    [ReAgnus-MegAChip.kicad_pcb]
2022-10-06 added OSHW silkscreen symbol
    [ReAgnus-MegAChip.kicad_pcb]
2022-10-07 changed to 0.5mm holes (from 0.6mm) due to board house requirement minimum spacing between hole and trace need to be 0.25mm
    [ReAgnus-MegAChip.kicad_pcb]
2022-11-28 Added schematic pdf
2022-11-29 fixed typo XLCK to XCLK on (XCLK/A20) net
    [ReAgnus-MegAChip.kicad_pcb, ReAgnus-MegAChip.sch, ReAgnus-MegAChip_FPGA.sch]
2023-07-25 footprints fixes
2023-07-25 Changed to 6 mil routing and to updated PLCC-footprint with 0.6mm pinholes and fixed dimensions for homebrew PLCC-84-plug
    [ReAgnus-MegAChip.kicad_pcb, ReAgnus-MegAChip.sch, ReAgnus-MegAChip_FPGA.sch]
2023-07-26 Added 3D-model of updated homebrew PLCC-84-plug with pinHeaders mounted
    [ReAgnus-MegAChip.kicad_pcb]
2023-07-27 Updated to new 3D-model of homebrew PLCC-84-plug
    [ReAgnus-MegAChip.kicad_pcb]
2024-04-14 Added more track-width options
2024-04-14 Changed pin-assignment for BLIT_3V3, WE_3V3, RW_3V3 and REGEN_3V3 signals on FPGA to ease routing.
    [ReAgnus-MegAChip_FPGA.sch]
2024-04-14 Changed level shifters from SN74CBTD16210DGGR (TSSOP-48) to SN74CBT16210CDGVR (TVSOP-48) and added a 4.3V LDO regulator TPS73643DBV and re-routed.
    [ReAgnus-MegAChip.kicad_pcb, ReAgnus-MegAChip.sch]
2024-04-14 Changed to a four layer stackup, GND and a 3V3 as inner layers, added a MountingHole_2.2mm_M2 for proper grounding via a ring lug connector on a thick jumper wire
    [ReAgnus-MegAChip.kicad_pcb, ReAgnus-MegAChip.sch]
2024-04-14 Removed the SDRAM chip and the crystal oscillator
    [ReAgnus-MegAChip.kicad_pcb, ReAgnus-MegAChip_FPGA.sch]
2024-04-18 Went to a 4-layer PCB and changed FPGA to GW1NR-UV9LQ144P with embedded PSRAM, changed FET-bus-switches to SN74CBT16210CDGVR (TVSOP-48) and added 4.3V LDO regulator TPS73643DBV and re-routed.
    [ReAgnus-MegAChip.kicad_pcb, ReAgnus-MegAChip.sch, ReAgnus-MegAChip_FPGA.sch]
2024-04-18 Moved signal nNTSC_8372_3V3 to pin FPGA pin 24
    [ReAgnus-MegAChip.kicad_pcb, ReAgnus-MegAChip_FPGA.sch]
2024-04-18 deleted old obsolete schematic
2024-05-07 Added a pull-up resistor R4 for pin 41 (PAL/NTSC-selector) because A500 Rev.6A doesn't have pull-up on motherboard, and bumped to Rev. 2B
    [ReAgnus-MegAChip.kicad_pcb, ReAgnus-MegAChip.sch]
2024-05-07 Updated schematic pdf
2024-05-08 Add pin-mapping file
2024-05-12 Moved signals from bank 3 to bank 0
    [ReAgnus-MegAChip.kicad_pcb, ReAgnus-MegAChip.sch, ReAgnus-MegAChip_FPGA.sch]
2024-05-12 Assigned DIR-signal to FPGA from U10 (74LVC245)
    [ReAgnus-MegAChip.kicad_pcb, ReAgnus-MegAChip_FPGA.sch]
2024-05-13 Added 1.8V SOT-23 LDO MCP1702T-1802E_CB
2024-05-13 Added 1.8V LDO MCP1702T-1802E_CB to feed VCCIO3 (pSRAM) + inductor and decoupling and fixed routing, added pull-up resistor for JTAG TDO
    [ReAgnus-MegAChip.kicad_pcb, ReAgnus-MegAChip.sch, ReAgnus-MegAChip_FPGA.sch]
2024-05-13 Bump version to Rev. 2C
    [ReAgnus-MegAChip.kicad_pcb]
2024-05-13 Add schematic pdf
2024-07-04 Changed L1 from inductor to ferrite bead 600 Ohms impedance, changed C6 to 10uF, C9 to 1uF, C27 to 0.1uF, C28 to 0.1uF
    [ReAgnus-MegAChip.kicad_pcb, ReAgnus-MegAChip.sch, ReAgnus-MegAChip_FPGA.sch]

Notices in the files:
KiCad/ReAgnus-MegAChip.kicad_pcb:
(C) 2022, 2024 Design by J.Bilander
